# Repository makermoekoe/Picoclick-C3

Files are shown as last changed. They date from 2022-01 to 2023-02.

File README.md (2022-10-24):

# Picoclick-C3

</a>
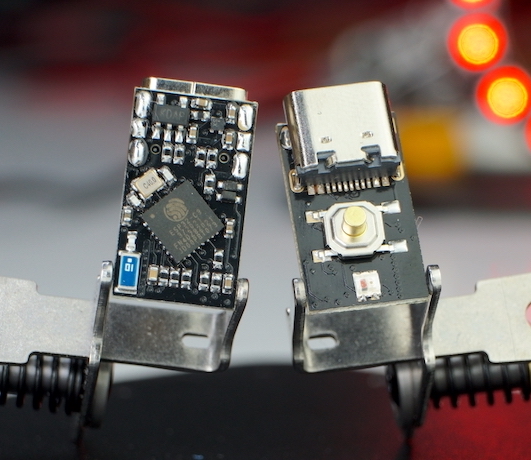
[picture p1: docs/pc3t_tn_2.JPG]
</a>

The Picoclick C3 as well as its little brother (the C3T, T = tiny) are the successors of the well known [Picoclick](https://github.com/makermoekoe/Picoclick). The name is related to its new processor: the [ESP32-C3](https://www.espressif.com/sites/default/files/documentation/esp32-c3_datasheet_en.pdf) single core RISC-V 160MHz CPU.

The Picoclick is a tiny WiFi and BLE IoT button for several applications. Originally designed for smart home things, the Picoclick can also be used as an actuator for IFTTT automations or as an MQTT device. It is based on the single core ESP32-C3 RISC-V processor and therefore comes with tons of useful features.
With dimensions of only 10.5mm by 18mm, the C3T is not only the smallest one in the family of the Picoclicks, it is also the smallest device I have created so far.

The [Youtube video of the C3T](https://www.youtube.com/watch?v=t-50w3RsUlg) shows the assembly and soldering process, the optimization of the boot up time, the power measurements as well as some useful applications of the Picoclick.

Here are some specs of the Picoclick C3T:
- Dimensions are only 10.5x18mm
- Ultra low standby current due to latching circuit (no sleep mode needed)
- Single button & LED interface (WS2812 RGB LED)
- USB Type-C for charging the battery and flashing the ESP32-C3



## Update 14.07.2022: The Picoclick C3 is alive!

It's a pleasure for me to announce that the Picoclick C3 (the big brother of the C3T) is finally here! It comes with the most advanced features of my latest projects which occupies the following points:

- Optimized idle current: we're below 200nA (!!) current consumption (without battery protection) in idle state! (compared to 3µA for the C3T)
- Optimized antenna design, which will lead to a better performance and longer range.
- Optimized power latching circuit, which makes the firmware development easier. (especially with the Arduino IDE)
- Optimized battery charging circuit with separated status LED.
- Added second RTC crystal.
- Added FPC connector for connecting external hardware.
- Added embedded battery protection.
- Added boot emergency jumper.
- Same dimensions as the standard Picoclick.
- Added a nice "golden" logo ;)

### [Main documentation of the Picoclick-C3 can be found here!](https://makermoekoe.gitbook.io/picoclick-c3/)

## GPIOs

Function | GPIO C3T | GPIO C3 | Mode
-------- | -------- | -------- | --------
LED | GPIO6 | GPIO6 (CLK) + GPIO7 (SDI) | Output
Latch* | GPIO3 | ** | Output
Button | GPIO5 | GPIO5 | Input
Charge Stat. | GPIO1  | ext. LED | Input
Bat Voltage | GPIO4 | GPIO4 | Input
Bat Voltage EN | -- | GPIO3 | Output

*Enabling the LDO can be done by pressing the button of the device or turning the latch high. In most use cases, the latch GPIO should be turned on as the first task of the Picoclick. Once the task is completed the device can be powered off by turning the latch off (e.g. pulling it low).

**The Picoclick C3 doesn't need a latching GPIO because it uses the embedded flash's power supply pin as a reference. It can be depowered with putting the ESP32 in deepsleep. To reduce the power consumption of the ESP32 this function will disable the power of the embedded flash (`VDD_SPI`) which in result will depower the Picoclick itself. The deepsleep calling function is only necessary to pulling the `VDD_SPI` line low, not to use the deepsleep mode of the ESP32.

## Reducing power consumption

In order to reduce the power consumption of the Picoclick the following points can be done:

- Disable WiFi while not in use (e.g. if using LED animations only): `WiFi.mode(WIFI_OFF);`
- Reducing CPU frequency after WiFi stuff is completed (crystal is 40MHz): `setCpuFrequencyMhz(10); //reduce to 10MHz`
- Reducing brightness of the LEDs (can be done right after FastLED init): `FastLED.setBrightness(150);`

## Board overview C3T (Battery connections)

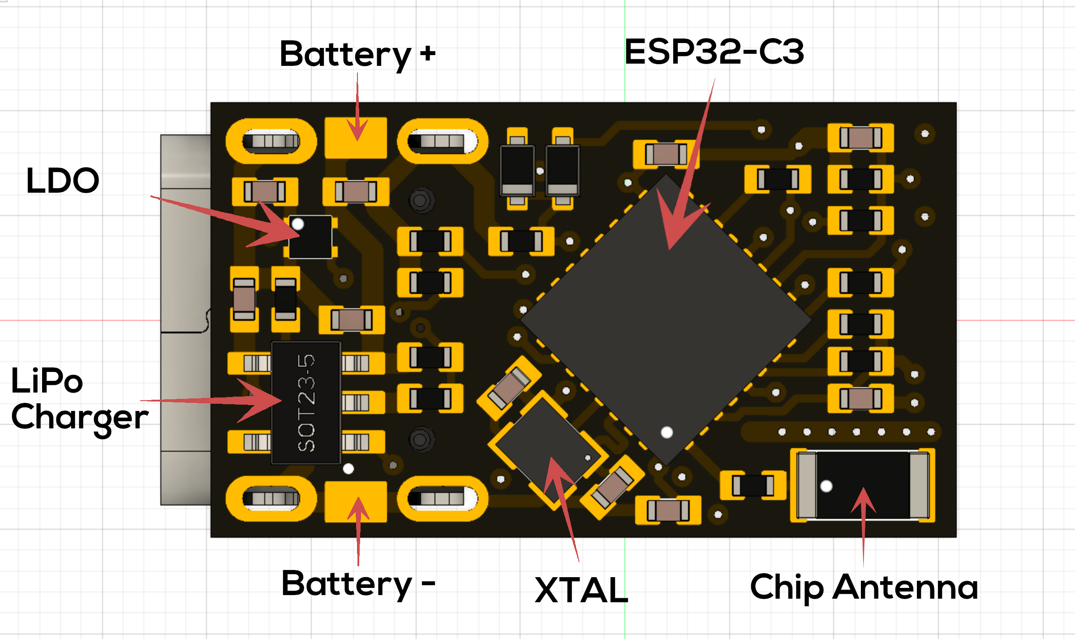
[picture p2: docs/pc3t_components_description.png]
</a>

## Flashing firmware to the ESP32 (C3T)

**- Press and hold the button during the complete flashing process! Otherwise the ESP32 will be loose power and the upload process will crash!**

**- A battery or a power supply has to be applied to the battery pads (3.5v - 5.5v) in order to flash the device!**

Except the above, the Picoclick behaves like a normal development board. No need to get the ESP32 into download mode or pressing any reset button.

## Speed up boot process

**Following instructions are only needed for the C3T, not for the C3 as it doesn't use a separate latching GPIO.**

Due to the latching circuit, the button press has to be longer than the boot up time of the processor, because the first task should have been executed once the button is released. For most of the use cases of the Picoclick the first task is to toggle the latch GPIO high in order to enable power hold feature of the Picoclick. If this task haven't been executed before the button is released, the Picoclick is going to standby mode without finishing its main task.
Standard boot up time of the ESP32-C3 is almost 300ms. So the first task will be executed after these 300ms. This is far too long because a standard button press (especially with the metal buttons on the C3T) is around 100ms-200ms or even slightly below. Almost every task of the Picoclick would have been interrupted in this case (unless you press and hold the button...).
To speed up the boot process I got familiar with the ```menuconfig``` of the ESP-IDF. Actually the reason why I've switched from the Arduino framework to ESP-IDF was that I get access to all the configs of the ESP32-C3.

Things I have done so far:
- Set *Flash SPI mode* from *DIO* to *QIO* (in Serial flasher config)
- Set *Log output* from *Info* to *Warning* (in component config)
- Set *Bootloader log verbosity* from *Info* to *Warning* (in Bootloader config)
- Enable *Skip image validation from power on* (in Bootloader config)

These points result in a boot up time of around 68ms which is almost quite fantastic. The test I've done so far were quite sufficient. If it is possible to make it even faster or if you have other ideas which could lead into the right direction then please let me know!

## Power consumption C3T

These power measurements are done with the Otii Arc power analyzer and its dedicated software. The average and peak current can be seen in the top right corner and is based on the selected frame in the current graph.
The Picoclick C3T is used as an ESP-NOW slave in this case, which is probably the fastest solution of any wireless connection.

A complete Picoclick task will look like this, whereby the LED part in the end is the longest part. The whole task took about 1,7 seconds, but the transmission itself is completed after around 200ms. The other part is with disabled WiFi and only used to do some visualizations with the LED. Overall average current is below 28mA.

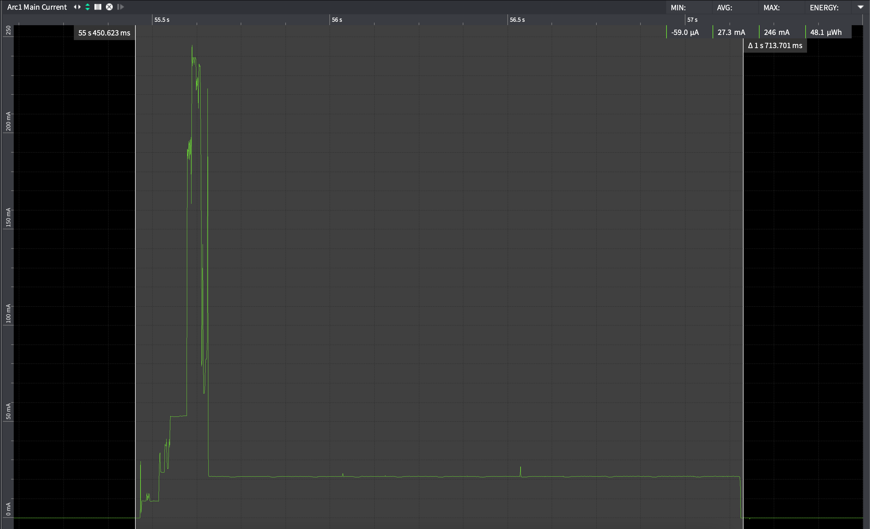
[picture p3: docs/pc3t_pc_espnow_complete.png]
</a>

The ESP-NOW package is sent in the first 200ms. Average current is 73mA here.

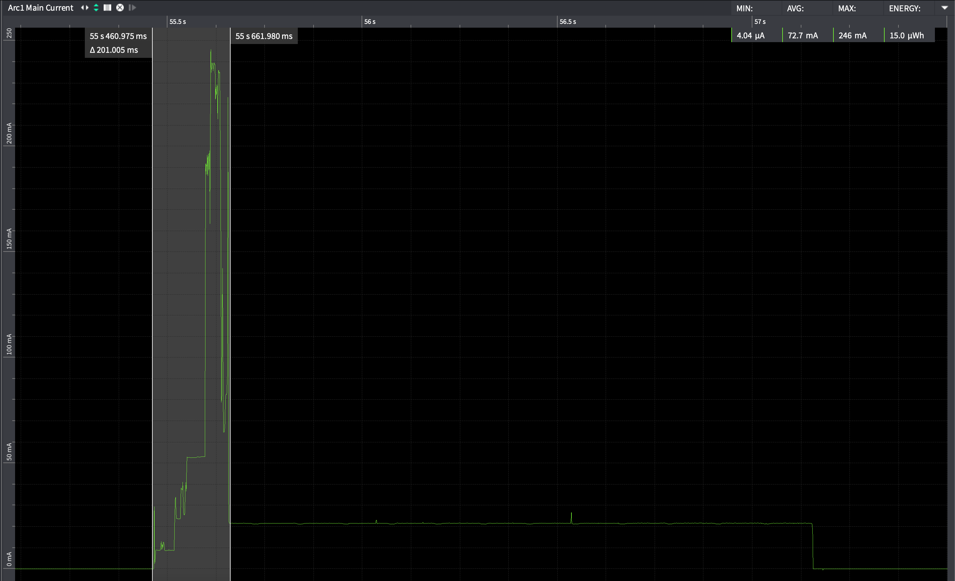
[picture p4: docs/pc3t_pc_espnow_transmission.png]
</a>

As already said, the rest is just visualization stuff which will use 22mA of current in average.

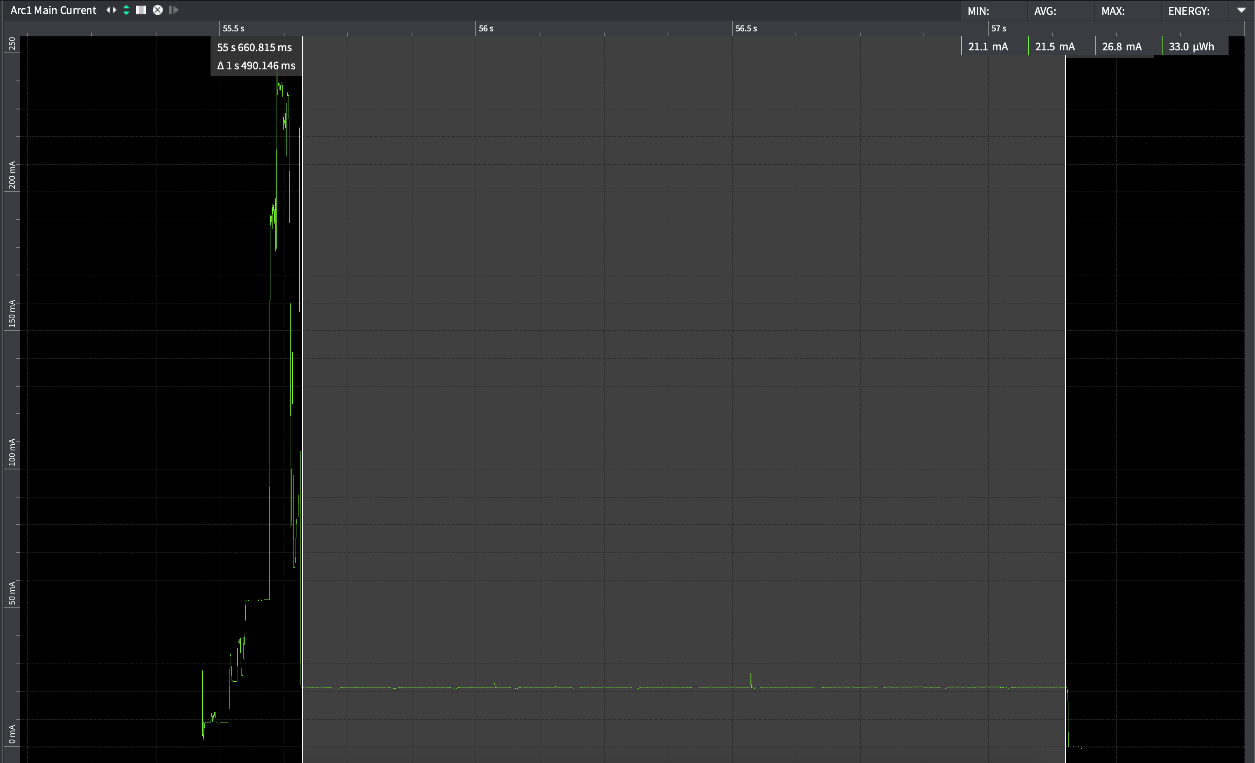
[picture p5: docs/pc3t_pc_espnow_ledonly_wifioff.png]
</a>

Probably the most interesting part is the standby current, because it's the most used state of the Picoclick. As the device doesn't use any sleep mode, we're getting as low as 3µA in this state. This is only related to the battery monitoring feature. As the voltage divider between ```Vbat``` and ```GND``` is ```1MOhm + 250kOhm = 1.25MOhm``` the current flow through it is about 3µA.

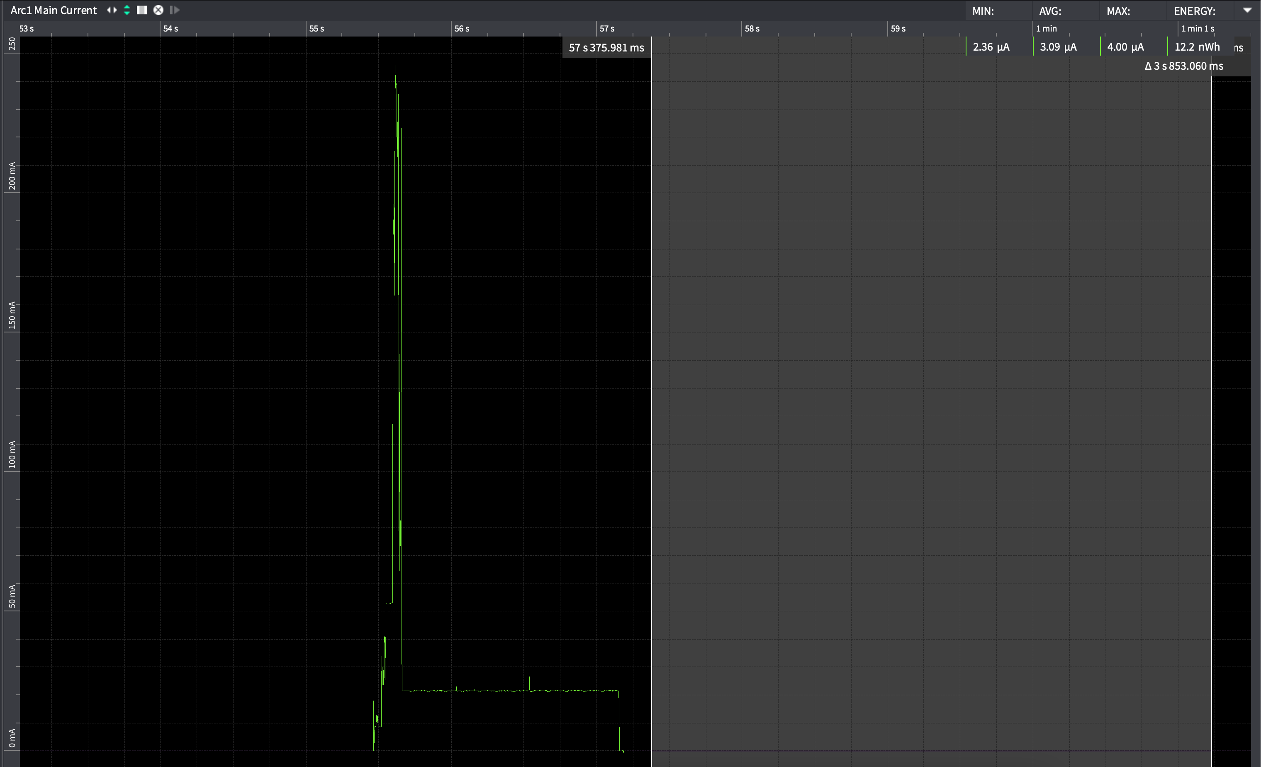
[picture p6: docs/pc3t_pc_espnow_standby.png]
</a>

## Battery for the Picoclick

### C3T

The optimal battery, which is shown in the picture below, is a 301012 LiPo battery (3.0mm thick, 10mm width, 12mm length). Nevertheless you can use whatever single cell LiPo battery you want. Charging current is set to 20mA, to be used with those 20-30mAh batteries. For larger capacity batteries the battery charging time will - of course - increase. For 20-30mAh charging time is about 1h - 1,5h.

Below are some links for those tiny batteries (no sponsor, no affiliate, just for info):

[Aliexpress 301012](https://de.aliexpress.com/item/1005003644834180.html)

[Aliexpress 401012](https://de.aliexpress.com/item/32794940086.html)

[eBay 301012](https://www.ebay.com/itm/333907143841)

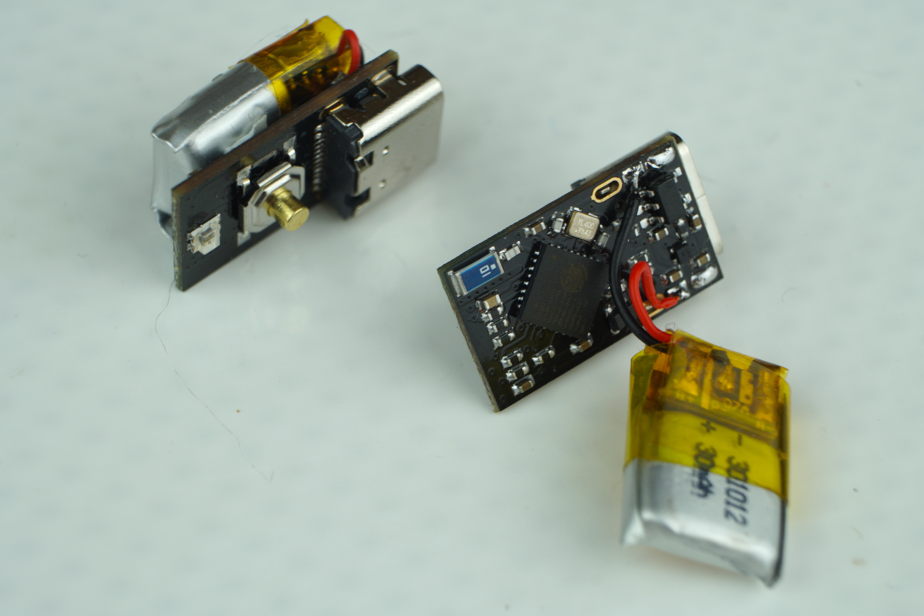
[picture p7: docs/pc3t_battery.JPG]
</a>

### C3

As the Picoclick C3 comes with an embedded battery protection, the protection of the LiPo battery itself is redundant. Therefore you can use these tiny cells which are used by BT headsets. They come in a 401010 or 301010 package.

[Aliexpress 401010](https://de.aliexpress.com/item/1005004324462178.html)

## Flashing adapter with pogopins for the C3T

In order to flash boards without soldering wires or batteries to the Picoclick, I decided to print a simple flashing adapter which uses 1mm pogopins to make contact to the battery pads on the board. Just plug in the USB cable, shift the device in, press it down to the pogopins and hit the upload button. Simple overview is given below.

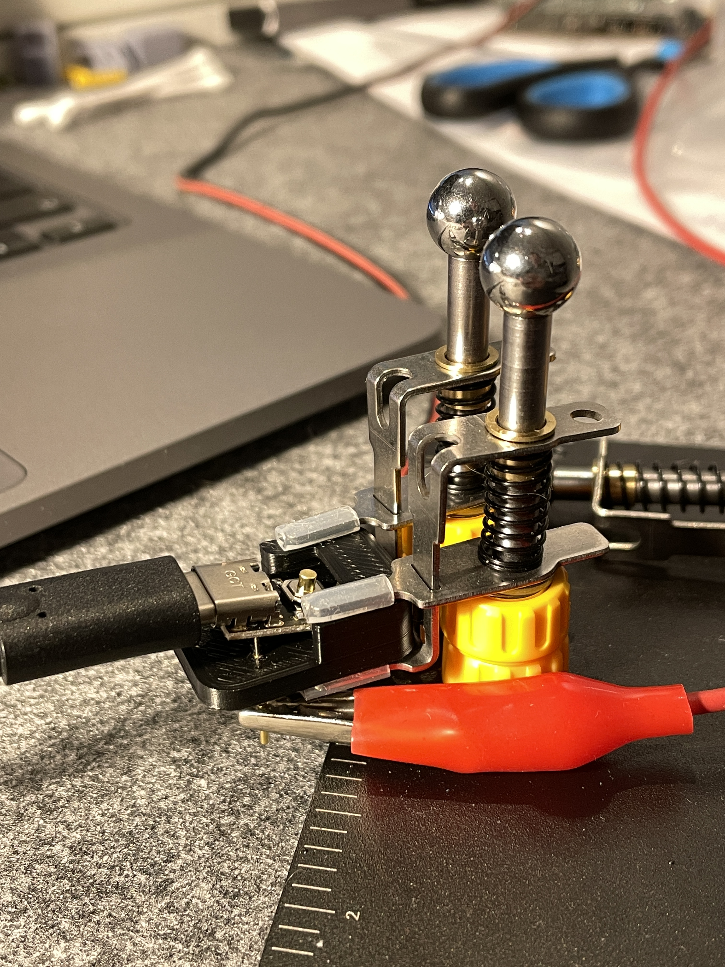
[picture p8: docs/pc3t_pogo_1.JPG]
</a>
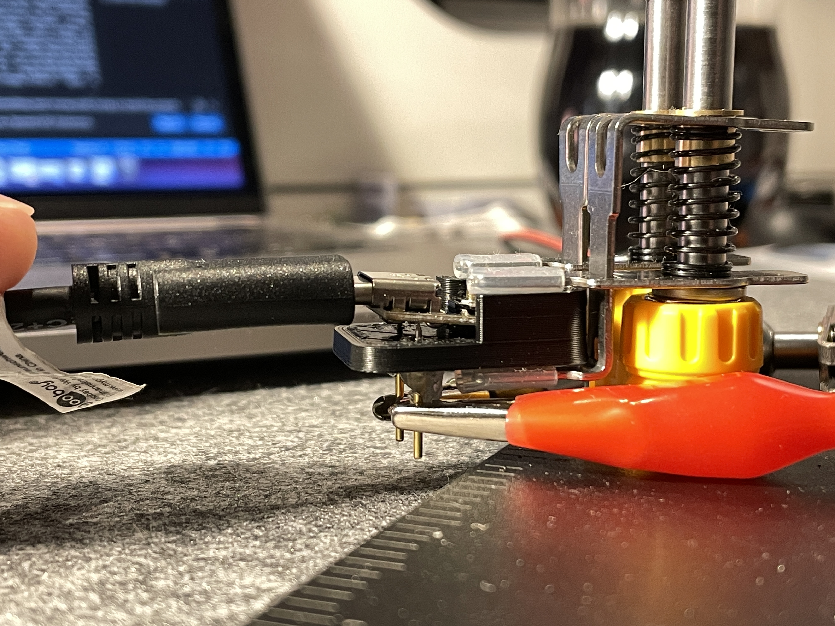
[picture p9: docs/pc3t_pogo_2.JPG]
</a>

## Cases for the C3T

Round design. Combined with two M2x8mm screws.

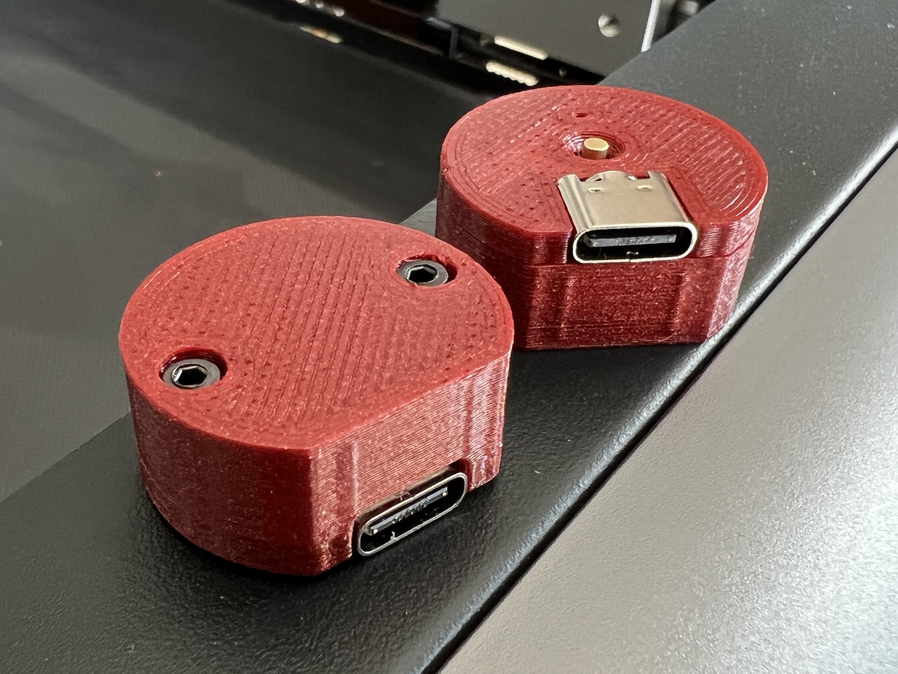
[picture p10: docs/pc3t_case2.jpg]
</a>

# FAQ

## My Picoclick C3T is not shown on the device list when I plug it in the computer - what can I do?
- Your Picoclick is well tested before shipping, so it is probably not broken. Make sure you have connected a decent power supply to the battery connections (3.5v - 5.5v). Battery polarity is shown above. The USB-C jack is only for charging the battery and to flash the ESP32 - not for powering the device.

## Media

Hackster.io article by James Lewis: [Picoclick C3T Is the World's Smallest IoT Button and It Has a RISC-V Processor](https://www.hackster.io/news/picoclick-c3t-is-the-world-s-smallest-iot-button-and-it-has-a-risc-v-processor-7eddb2c14bda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)

Electronics-lab.com article by Abhishek Jadhav: [Picoclick C3T IOT button built around ESP32-C3 RISC-V processor – supports WIFI and BLE](https://www.electronics-lab.com/picoclick-c3t-iot-button-built-around-esp32-c3-risc-v-processor-supports-wifi-and-ble/)

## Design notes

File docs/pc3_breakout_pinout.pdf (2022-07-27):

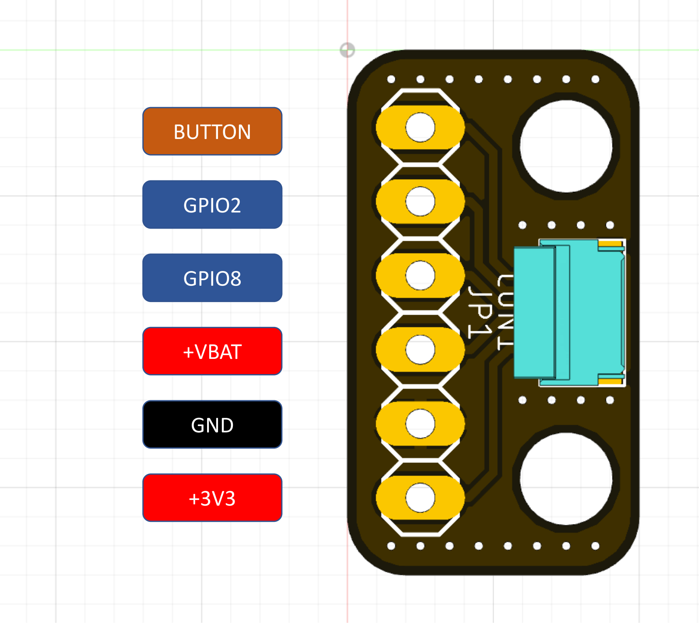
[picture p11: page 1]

+3V3

+VBAT

GND

GPIO2

GPIO8

BUTTON

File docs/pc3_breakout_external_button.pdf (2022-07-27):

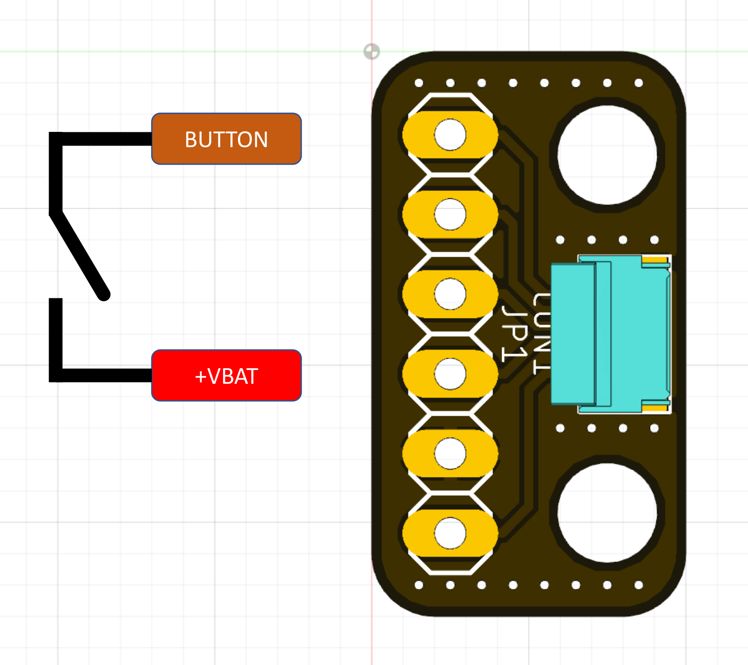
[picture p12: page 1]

+VBAT

BUTTON

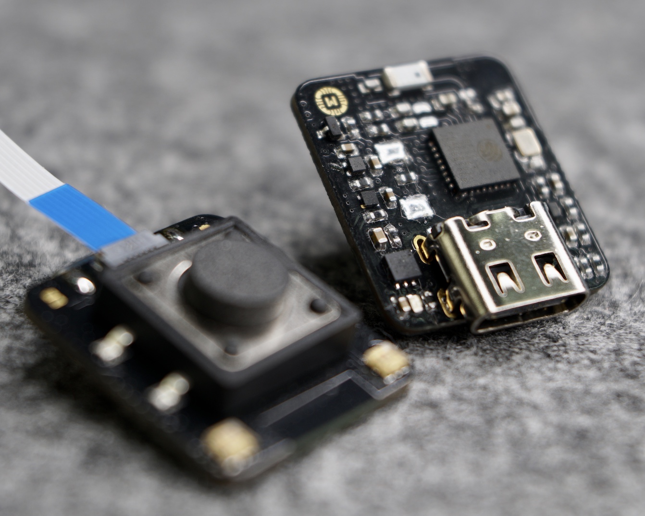
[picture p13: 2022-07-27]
docs/pc3_overview.jpg

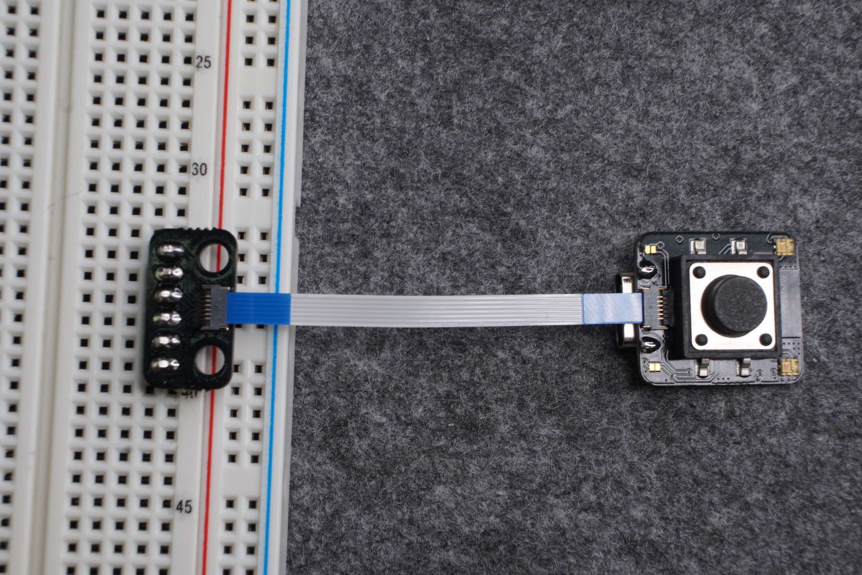
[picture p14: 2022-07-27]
docs/pc3_extensionboard.JPG

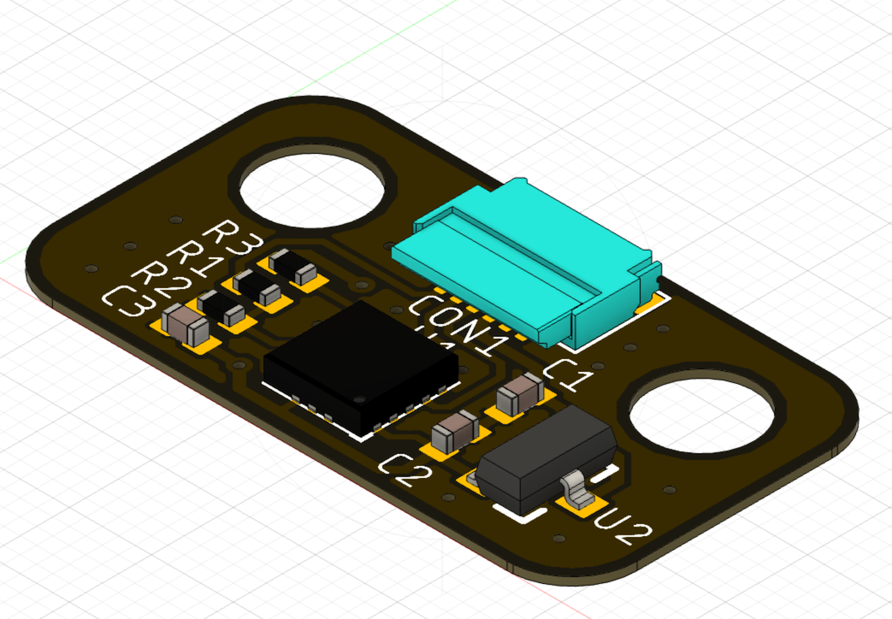
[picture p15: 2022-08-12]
docs/ext_board_lis.png

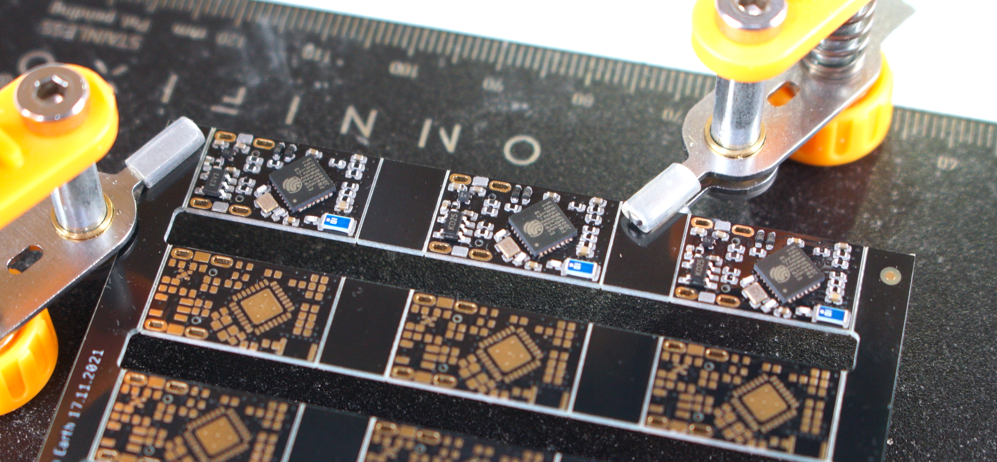
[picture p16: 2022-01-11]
docs/pc3t_panel_paste.JPG

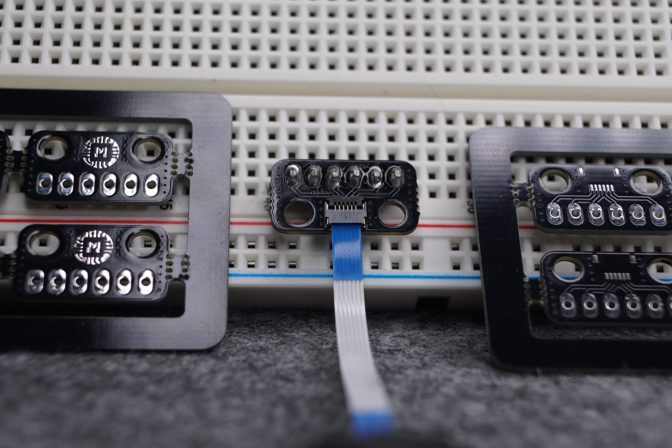
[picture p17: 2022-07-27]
docs/pc3_extensionboard2.JPG

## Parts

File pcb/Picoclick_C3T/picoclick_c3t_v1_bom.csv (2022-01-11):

Part | Value | Device | Package | Description
BAT+ | TP/SP-1.5X1.0 | TP/SP-1.5X1.0 | SOLDERPAD_1.5X1.0 | Solderpads/Testpads
BAT- | TP/SP-1.5X1.0 | TP/SP-1.5X1.0 | SOLDERPAD_1.5X1.0 | Solderpads/Testpads
C1 | 1µ | C-EU-0402-WOKEEPOUT_S | C0402_S
C2 | 1µ | C-EU-0402-WOKEEPOUT_S | C0402_S
C3 | 1µ | C-EU-0402-WOKEEPOUT_S | C0402_S
C4 | 1µ | C-EU-0402-WOKEEPOUT_S | C0402_S
C7 | 10µ | C-EU-0402-WOKEEPOUT_S | C0402_S
C8 | 0,1µ | C-EU-0402-WOKEEPOUT_S | C0402_S
C9 | 0,1µ | C-EU-0402-WOKEEPOUT_S | C0402_S
C13 | 1µ | C-EU-0402-WOKEEPOUT_S | C0402_S
C20 | 10p | C-EU-0402-WOKEEPOUT_S | C0402_S
C21 | 10p | C-EU-0402-WOKEEPOUT_S | C0402_S
D1 | 4148 | DIODE-SOD523 | SOD523 | DIODE
D2 | 4148 | DIODE-SOD523 | SOD523 | DIODE
ESP1 | ESP32_C3_QFN32 | ESP32_C3_QFN32 | QFN32
F2 | 0 | R-EU-0402-WOKEEPOUT | R0402
L1 | WS2812_2020 | WS2812_2020 | WS2812_2020
R/1 | 1M | R-EU-0402-WOKEEPOUT | R0402
R/2 | 250k | R-EU-0402-WOKEEPOUT | R0402
R1 | 1k | R-EU-0402-WOKEEPOUT | R0402
R2 | 1k | R-EU-0402-WOKEEPOUT | R0402
R3 | 1M | R-EU-0402-WOKEEPOUT | R0402
R4 | 10k | R-EU-0402-WOKEEPOUT | R0402
R5 | 47.5k | R-EU-0402-WOKEEPOUT | R0402
R7 | 10k | R-EU-0402-WOKEEPOUT | R0402
R10 | 10k | R-EU-0402-WOKEEPOUT | R0402
R11 | 10k | R-EU-0402-WOKEEPOUT | R0402
R12 | 5.1k | R-EU-0402-WOKEEPOUT | R0402
R13 | 5.1k | R-EU-0402-WOKEEPOUT | R0402
RF | ANT3216LL00R2400A | ANT3216LL00R2400A | ANT3216LL00R2400A
U$1 | BUTTON_ST-1187-3 | BUTTON_ST-1187-3 | BUTTON_ST-1187-3
U1 | BRCL4054BME | MCP73831_SOT23_5 | SOT23-5
U2 | MIC5504 | MIC5504 | TDFN4
USB-C | USB_C_C393939 | USB_C_C393939 | USBC_C393939
X1 | XTAL_2016 | XTAL_2016 | XTYL_2016

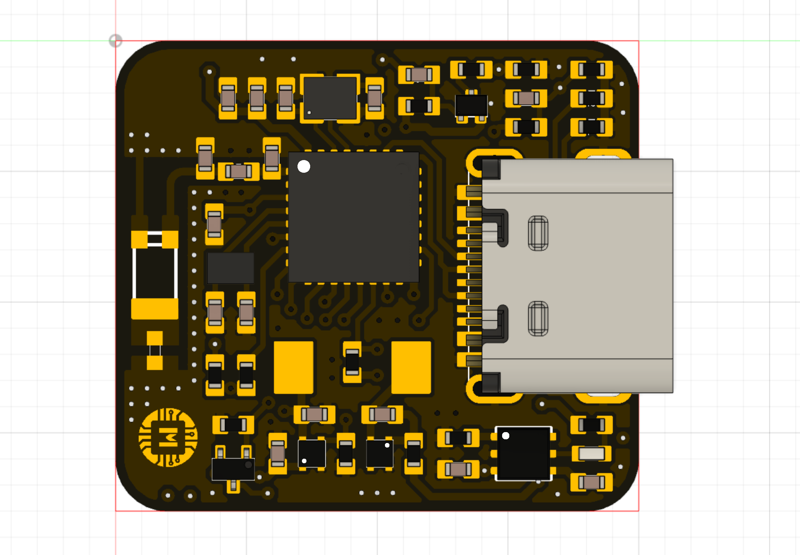
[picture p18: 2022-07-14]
docs/pc3_components_description.png

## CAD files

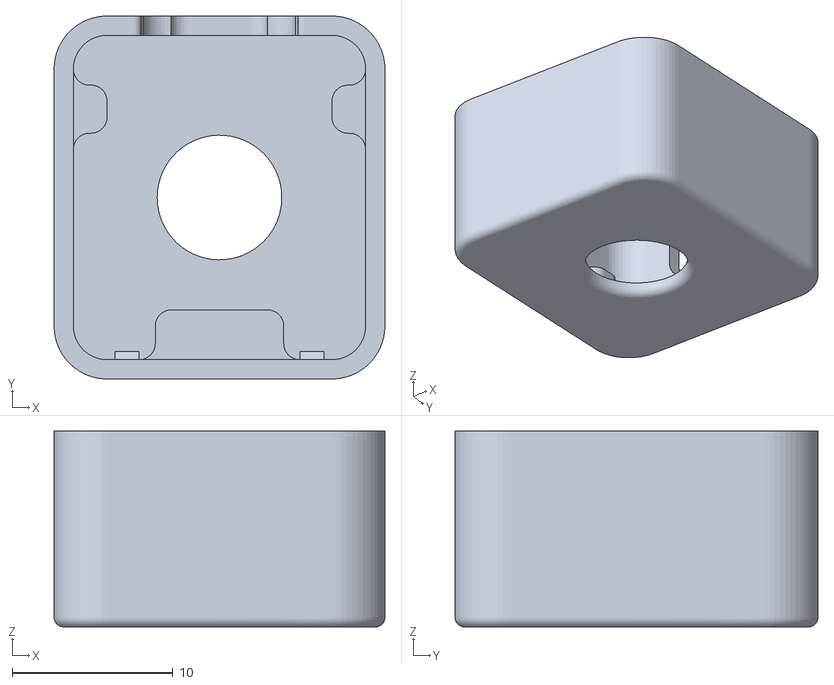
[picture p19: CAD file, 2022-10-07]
case/Picoclick_C3/case1_clear/picoclick_c3_clear_top_batspace_lock.stl
20.6 x 22.6 x 12.2

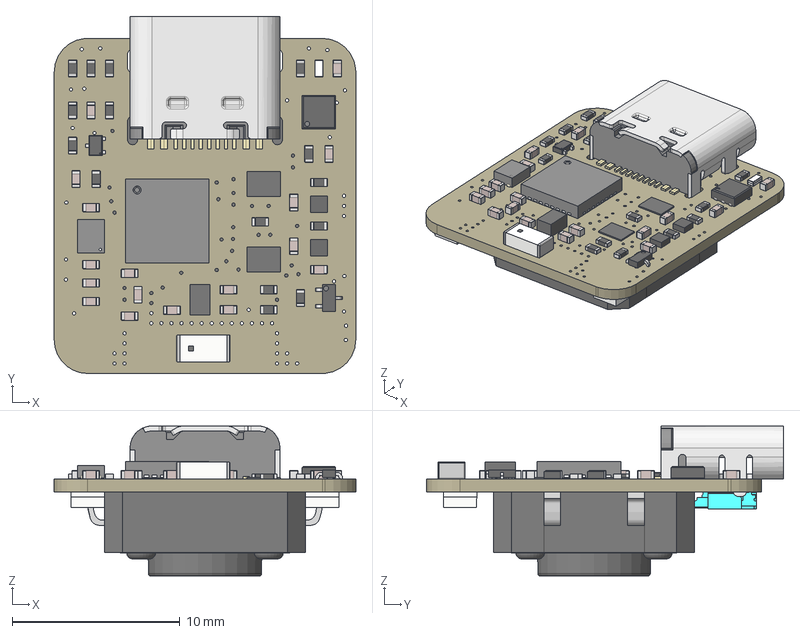
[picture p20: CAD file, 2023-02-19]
case/Picoclick_C3/PC3_3Dmodel.step
18.0 x 21.3 x 8.95 mm
Board
QFN32
SOT523
SOT723+1123
XTAL_2016
FH34SRJ-6S-0.5SH(50)
ConPins
PcbPins
Mold
Frame
DFN-6
TDFN4
Light
Cathode Mark
Anode Pin
Cathode Pin
Base
JUMPER_SMALL
BUTTON_SMD_12MM
JUMPER_SMALL (1)
R0402 (1)
TDFN4 (1)
XTAL_1016
SOLDERPAD_1.5X2.0 x 2
RFECA3216060A1T_NEW3_M
C0402_S x 14
R0402 x 14
C0402_S (1) x 3

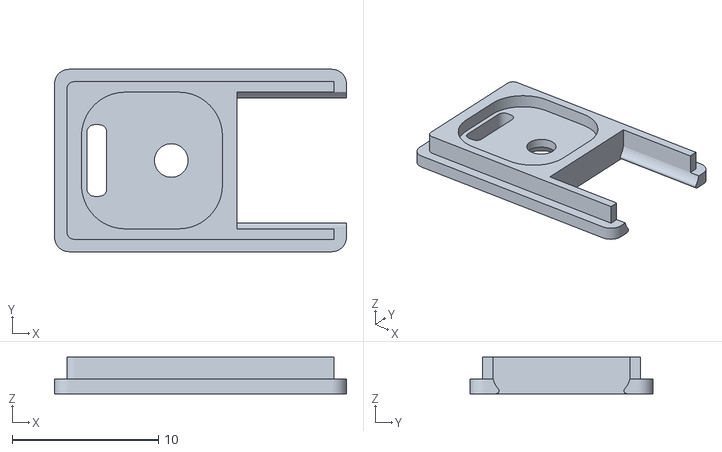
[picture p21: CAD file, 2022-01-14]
case/Picoclick_C3T/case1/pc3t_case1_top.stl
20.0 x 12.5 x 2.50

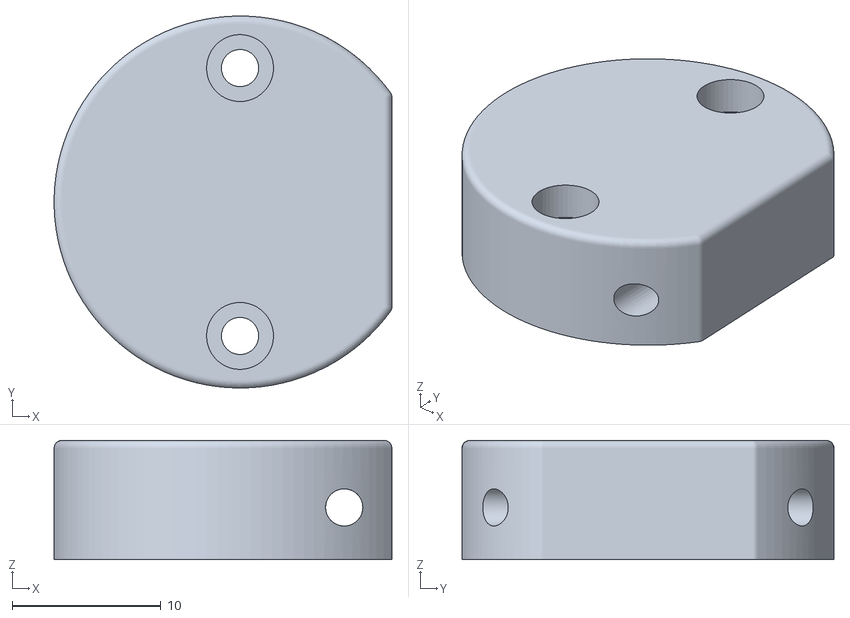
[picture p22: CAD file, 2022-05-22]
case/Picoclick_C3T/case2_round/pc3t_case2_round_bot_keyring2.stl
22.7 x 25.0 x 8.00

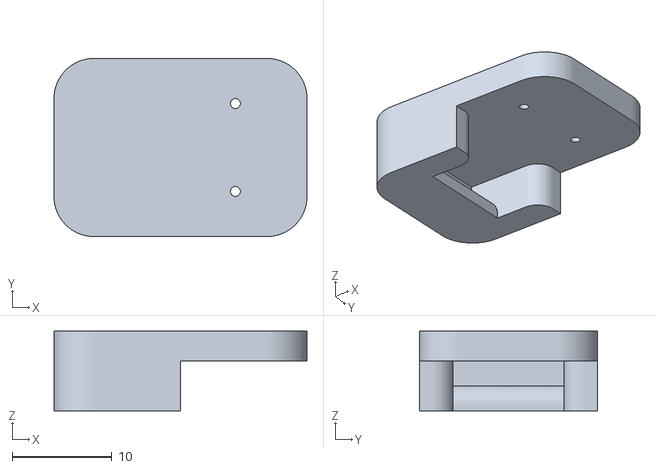
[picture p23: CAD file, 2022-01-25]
case/Picoclick_C3T/Picoclick_C3T_Flash_Pogo_Adapter.stl
25.3 x 17.8 x 8.00

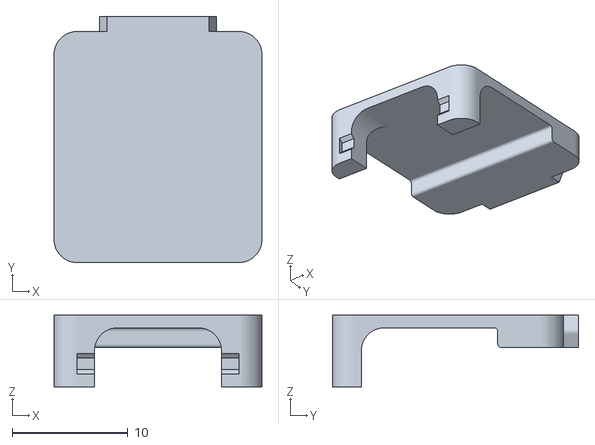
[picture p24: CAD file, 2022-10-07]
case/Picoclick_C3/case1_clear/picoclick_c3_clear_bot_batspace_lock.stl
18.0 x 21.3 x 6.21

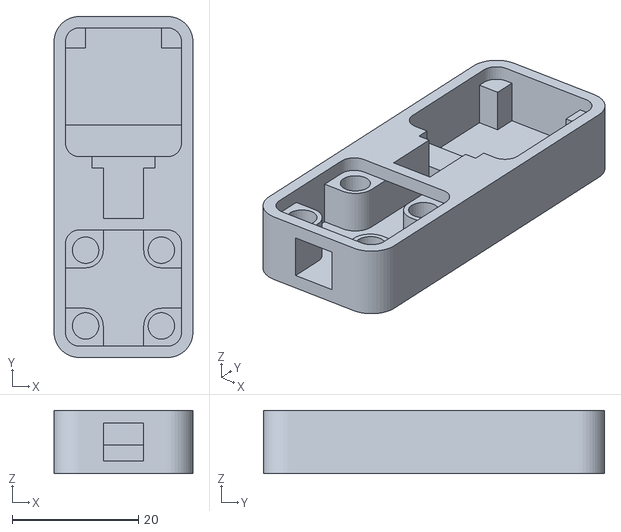
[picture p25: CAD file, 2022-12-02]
case/Picoclick_C3/pc3_ext_pir_v1.stl
22.0 x 54.0 x 10.00

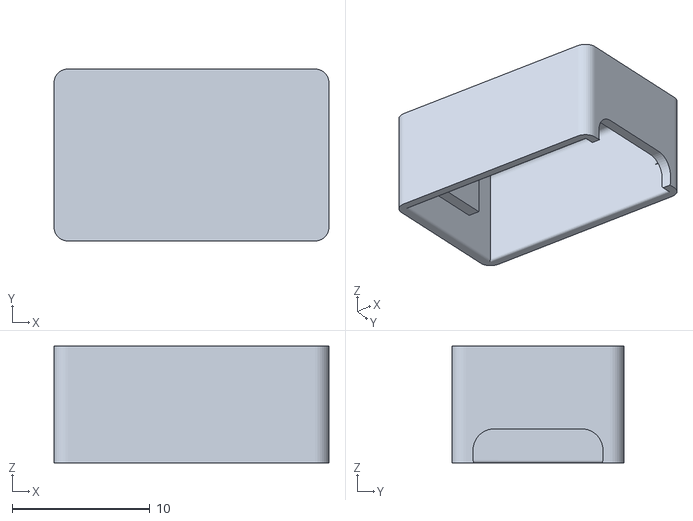
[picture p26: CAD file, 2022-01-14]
case/Picoclick_C3T/case1/pc3t_case1_bot.stl
20.0 x 12.5 x 8.50

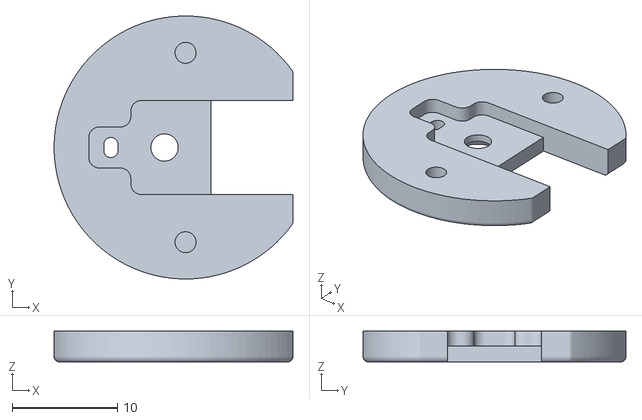
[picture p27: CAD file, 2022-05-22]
case/Picoclick_C3T/case2_round/pc3t_case2_round_top.stl
22.7 x 25.0 x 2.93

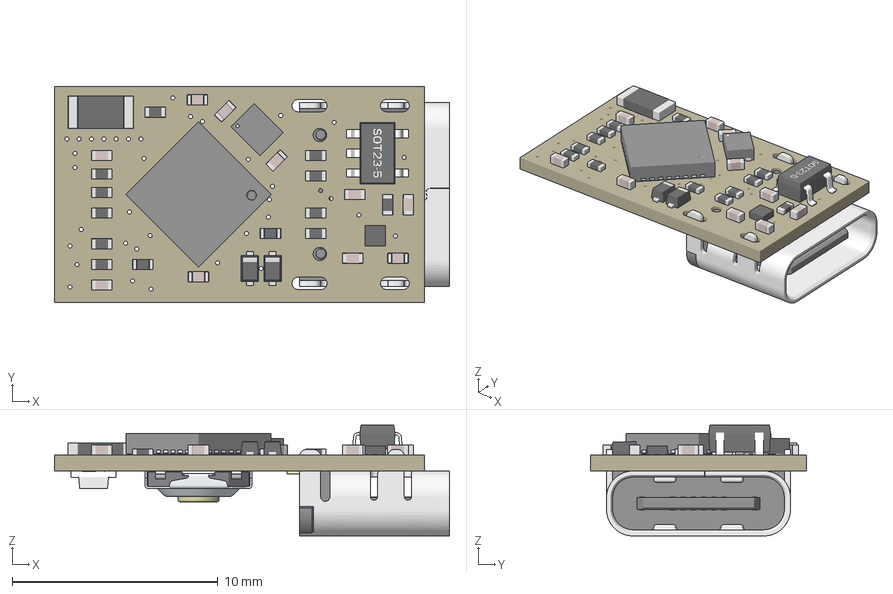
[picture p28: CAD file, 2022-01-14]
case/Picoclick_C3T/Picoclick_C3T_PCB.3mf
19.2 x 10.5 x 5.39 mm
Board
Körper1 x 36
Körper10
Körper11
Körper12
Körper13
Körper14
Körper15
Körper16
Körper17
Körper18
Körper19
Körper2 x 2
Körper20
Körper21
Körper22
Körper23
Körper24
Körper25
Körper26
Körper27
Körper28
Körper29
Körper3 x 2
Körper30
Körper31
Körper32
Körper33
Körper34
Körper35
Körper36
Körper37
Körper38
Körper39
Körper4 x 2
Körper40
Körper41
Körper42
Körper43
Körper44
Körper45
Körper46
Körper47
Körper48
Körper49
Körper5 x 2
Körper50
Körper51
Körper52
Körper53
Körper54
Körper55
Körper56
Körper57
Körper58
Körper59
Körper6 x 2
Körper60
Körper61
Körper62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

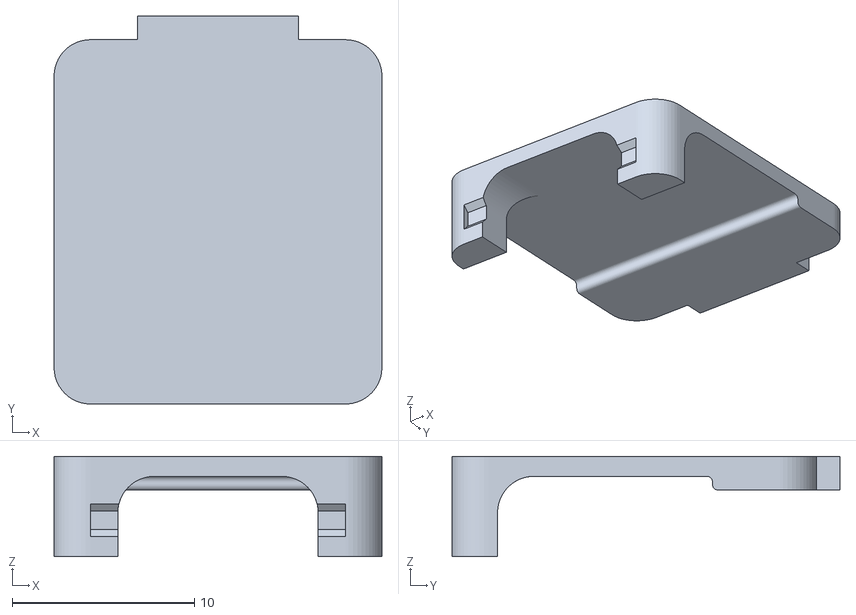
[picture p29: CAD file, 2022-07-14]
case/Picoclick_C3/case1_clear/picoclick_c3_clear_bot.stl
18.0 x 21.3 x 5.51

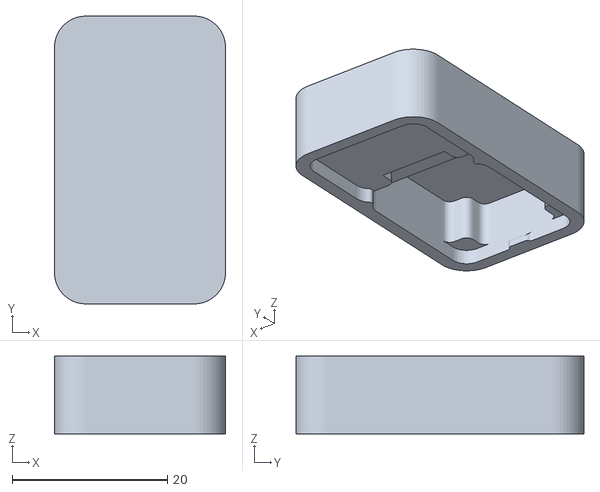
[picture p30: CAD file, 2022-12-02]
case/Picoclick_C3/pc3_ext_oled049_v1.stl
22.0 x 37.0 x 10.00

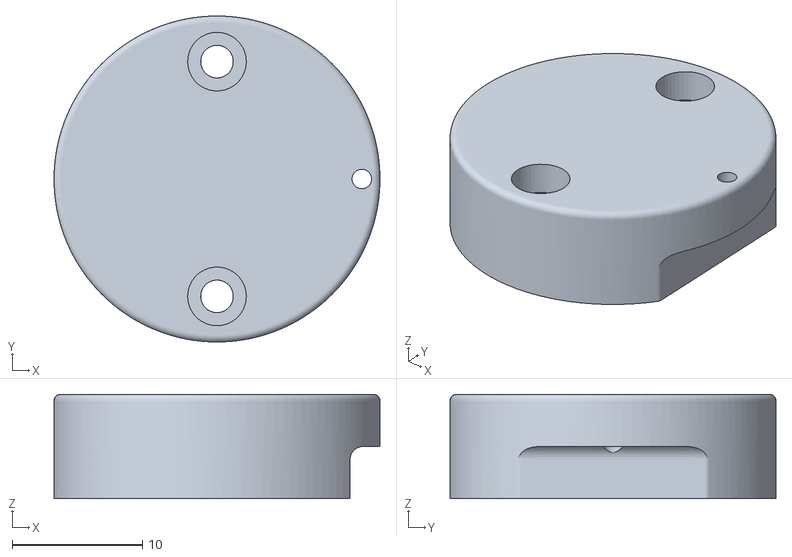
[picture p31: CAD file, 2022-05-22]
case/Picoclick_C3T/case2_round/pc3t_case2_round_bot_keyring1.stl
25.0 x 25.0 x 8.00

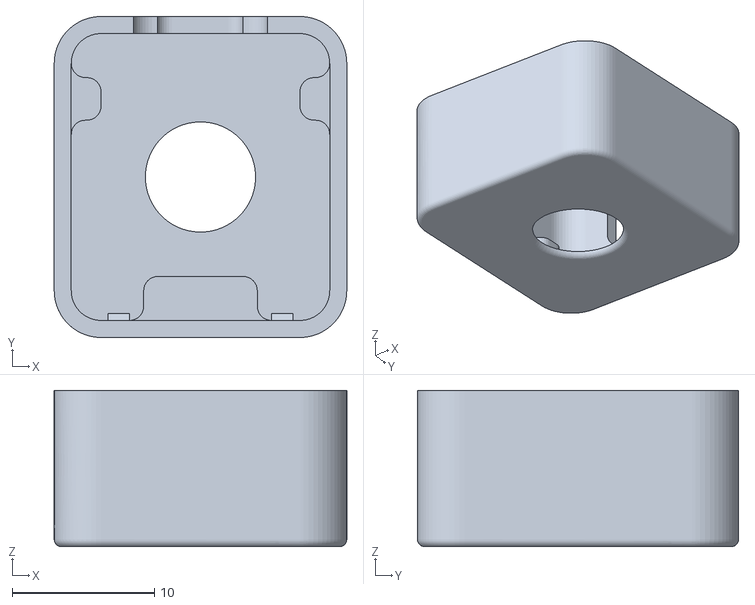
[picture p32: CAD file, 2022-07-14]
case/Picoclick_C3/case1_clear/picoclick_c3_clear_top.stl
20.6 x 22.6 x 11.0

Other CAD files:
case/Picoclick_C3/pc3_ext_motion_v2.stl
case/Picoclick_C3T/case2_round/pc3t_case2_round_bot.stl
case/Picoclick_C3/pc3_pogopin_adapter_bat_v1.stl
case/Picoclick_C3T/Picoclick_C3T_PCB.f3z
case/Picoclick_C3T/Picoclick_C3T_PCB.stl

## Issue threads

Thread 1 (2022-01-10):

Where can I buy one or two

8bignic8, 2022-01-10:
Hey is it possible to buy one or more. We could use it in our Hackerspace :). Greetings nice project.

makermoekoe, 2022-01-11:
Currently working on my own tindie store. It should be available in a couple of days. Nevertheless, I'm currently waiting for some components to arrive so the stock is not huge at the moment but will increase in 2-3 weeks.

Closed 2022-01-11.

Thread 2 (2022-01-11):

Have BOM list ?

Witawat, 2022-01-11:
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
What part F1 and F2 ?

thankyou

frollard, 2022-01-11:
https://www.espressif.com/sites/default/files/documentation/esp32-c3_hardware_design_guidelines_en.pdf

page 11: section 2.5 RF hardware design notes - "add a pi matching network for antenna matching, preferably CLC network." Parts tbd based on actual pcb.

makermoekoe, 2022-01-11:
Tradeoff between device size and fully matchable antenna. So it's not a complete pi network but nevertheless seems to work fine for this four layer board with its dimensions.

BOM is added.

Closed 2022-01-11.

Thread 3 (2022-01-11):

Not espressif but impressive

pshobowale, 2022-01-11:
1.) On the question if you could improve the performance:
Are there still boot messages if you look at the serialport? Because if there are you could try to completely disable them as this wastes time during startup. --> https://esp32.com/viewtopic.php?t=24244 and https://www.esp32.com/viewtopic.php?t=1658 (don't know if it is the same procedure as for the c3)

2.) How much longer is the boot time if you validate the boot image, because this could be a possible backdoor?

3.) May I use you your design for a private project? (I want to try to build a kind of opensource alternative to this --> https://freedrum.rocks/)

septatrix, 2022-01-19:
You could also take a look inside the [`esp_system/startup.c`](https://github.com/espressif/esp-idf/blob/1d02e638bd05b80d6fd648d51c14a8ecd6c2dbdc/components/esp_system/startup.c)¹ file and try some of the other hooks there. It seems like using `__attribute__(constructor)`, `__attribute__ ((section(".initX"))` or `ESP_SYSTEM_INIT_FN` should all provide you with earlier places to enable the power latch. The earliest hook seems to be to define a custom `start_cpu0` and inside that call `start_cpu0_default` to continue the normal boot process. I am not quite sure if some initialization has to be performed before the gpio is usable via the usual functions so some of the more drastic/early hooks might not work or you would need to write to the raw registers instead. Anyway if you want to register even shorter button presses this might help. If you have any question feel free to ask me (also in german ;D).

¹ Potentially also [`esp_system/port/cpu_start.c`](https://github.com/espressif/esp-idf/blob/1d02e638bd05b80d6fd648d51c14a8ecd6c2dbdc/components/esp_system/port/cpu_start.c) though I doubt you can hook into there - also the system is very much uninitialized that early.

makermoekoe, 2022-01-24:
There aren't any messages while the ESP is booting anymore. Nevertheless, the easier way is to disable them completely, yes...

I don't now it anymore because I have tested so many things on that day back then. I should definitely measure it again and check if it's worth it.

And as I have not yet set any license here you can actually use whatever you want!

makermoekoe, 2022-01-24:
> You could also take a look inside the [`esp_system/startup.c`](https://github.com/espressif/esp-idf/blob/1d02e638bd05b80d6fd648d51c14a8ecd6c2dbdc/components/esp_system/startup.c)¹ file and try some of the other hooks there. It seems like using `__attribute__(constructor)`, `__attribute__ ((section(".initX"))` or `ESP_SYSTEM_INIT_FN` should all provide you with earlier places to enable the power latch. The earliest hook seems to be to define a custom `start_cpu0` and inside that call `start_cpu0_default` to continue the normal boot process. I am not quite sure if some initialization has to be performed before the gpio is usable via the usual functions so some of the more drastic/early hooks might not work or you would need to write to the raw registers instead. Anyway if you want to register even shorter button presses this might help. If you have any question feel free to ask me (also in german ;D).
>
> ¹ Potentially also [`esp_system/port/cpu_start.c`](https://github.com/espressif/esp-idf/blob/1d02e638bd05b80d6fd648d51c14a8ecd6c2dbdc/components/esp_system/port/cpu_start.c) though I doubt you can hook into there - also the system is very much uninitialized that early.

You genius. Initially the voltage divider workaround and then the idea with the early switching latch haha! Yes, I have read something about the second stage bootloader and that it is possible to do actions there as well. Regarding the serial output while booting this action would take place after 27ms. And when disabling serial output this would even be more early. But as I'm new to the ESP-IDF this is a task in the future only...

Not sure if you have ordered a Picoclick, but if yes it would be nice to get support in this 🙂

septatrix, 2022-01-24:
> You genius. Initially the voltage divider workaround and then the idea with the early switching latch haha!

Thanks, I feel flattered :)

> Not sure if you have ordered a Picoclick, but if yes it would be nice to get support in this 🙂

Not currently, no. I wanted to wait if there might be some hardware revision should the voltage divider be improvable or maybe even slightly modify the board to allow for two buttons and build it myself to save a few bucks.

However I have a normal ESP32 lying around with which I could try some stuff. I won't be able to get any absolute timings as I have no access to an osci but I already have some other ideas in mind to get relative timings.

septatrix, 2022-01-24:
> And as I have not yet set any license here you can actually use whatever you want!

As far as I know you retain every right to the content in this repo without a license meaning that redistributing, modifying etc is prohibited (https://opensource.stackexchange.com/a/1721). I am not well versed with hardware licenses though there should also be some permissive ones you might consider choosing from.

septatrix, 2022-02-12:
The entry points I initially planned to target only yielded small improvements of a few milliseconds at most while being very hacky and using undocumented/internal apis.
However the second stage bootloader seems very promising as it exposes a before/after hook which can be used. The `bootloader_before_init` hook fires after only 850210 cycles on my standard ESP32 which would be about ~5ms@160MHz. The RISC-V core will differ slightly though likely not by much. Sadly I have not been able to convince PlatformIO to also build the second stage bootloader but when directly using idf.py everything seems to work flawless.
Next steps would be to configure some IO pins as the normal GPIO component is not yet initialized so we have to access the registers directly. This should be fairly simply.

I also made an issue about more init hooks before stumbling upon the bootloader hooks where @igrr also suggested simply using a GPIO pin which defaults to a weak pull-up. This could then be made into a low output to disable the latch again. I do not quite grasp the whole latching mechanism and therefore do not know if such a weak pull-up would be sufficient (or if a pull-down would be required which does not seem to be the default state for any of the pins). For anyone interested here the issue: https://github.com/espressif/esp-idf/issues/8390

Closed 2022-04-19.

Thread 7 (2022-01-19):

Rotary Encoder Push Button

paulwratt, 2022-01-19:
Is there enough room (GPIO) to adapt this board this to either:
- rotary encoder
- rotary encoder with push button

DuckDuckGo: [electronics rotary push button](https://duckduckgo.com/?q=electronics+rotary+push+button)

Cheers

Paul

Closed 2022-02-15.

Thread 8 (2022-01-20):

Is the battery voltage checked anywhere?

septatrix, 2022-01-20:
In the README it says that most standby current is used by the voltage divider connected to the battery which according to the schematics is connected only to the ESP32. However in the code I can find no usage of that pin except for the defines. Is there maybe some other place where this information is used? I plan to create my own iot button inspired by you project and if it is not need I consider dropping the voltage divider.

makermoekoe, 2022-01-21:
Well, the battery divider is not needed when don't care about the battery state. It's there to read the batteries voltage level und thus estimate the state of the battery (like in percentage). You could, for example, disable WiFi if the battery state is too low to protect it from being overdischarged, or it least discharged too much, because there is a battery protection which protects it from overdischarge. Another example is to send the battery state out so that you can visualize it somewhere else, like it is also done with smart home remotes or PIRs.

In the included sketches the battery state is not used yet, yes, but I will update this as soon as possible (hopefully on this weekend). It's as easy as reading the GPIO4 (ADC1_CH4) and convert it to a voltage with consideration to the divider.

septatrix, 2022-01-21:
Thanks for the reply. So if it is only used by the ESP32 would it not be possible to put a low-leakage transistor between the voltage divider and ground or connect the ground of the voltage divider to a pin of the ESP32 which could be pulled low when needed¹? Given that it draws a majority of the standby current it would increase the lifetime per charge significantly.

¹ This would of course only work if the GPIO would be in input or high-impedance mode when unpowered though I have not yet found official information regarding that behaviour.

makermoekoe, 2022-01-24:
For the first version of the Picoclick (not the C3 version) I tried to connect the voltage divider to a GPIO on the GND side and turn it low while reading the voltage. Somehow I took a wrong GPIO (probably a floating or a default low one), which was so frustrating that I didn't reconsider working on this again...
But now, as it is clear that it was just a wrong chosen GPIO, I will definitely try to implement something like this again! 3µA are still too much...

Btw. I have updated the code which can now read the battery voltage. It is as easy as this:

Setup:
`#define ADC_PIN ADC1_CHANNEL_4
  adc1_config_width(ADC_WIDTH_12Bit);
  adc1_config_channel_atten(ADC_PIN, ADC_ATTEN_0db);`

and to read the voltage (in mV):
`int voltage_mv = adc1_get_raw(ADC_PIN);`

septatrix, 2022-01-24:
> For the first version of the Picoclick (not the C3 version) I tried to connect the voltage divider to a GPIO on the GND side and turn it low while reading the voltage. Somehow I took a wrong GPIO (probably a floating or a default low one), which was so frustrating that I didn't reconsider working on this again... But now, as it is clear that it was just a wrong chosen GPIO, I will definitely try to implement something like this again! 3µA are still too much...

Isn't a floating pin exactly what you want or more specifically high impedance (the third state apart from input/output)? Output-low would not yield an improvement, output-high would probably either damage the ADC pin when the μC has power or at least be equivalent to output-low without power. Input on the other hand might also damage the controller? Though I am tapping a bit in the dark here as one does not deal with powerless μCs every day and just imagining what might be possible. High impedance should behave as close to an unconnected pin as possible though I am also not sure what voltage the ADC would be exposed to in that scenario.

The safest bet would probably be a transistor with a big pull-down between the voltage divider and GND (as well as maybe also the midpoint and ADC - again no clue what voltage would be there otherwise).The base of the transistor(s) would be connected to an output-low, input or high impedance pin of the ESP32 with a big pull-down in the latter cases to prevent the pin from floating. As such the pd should not draw significant power. It might also be possible to use a single transistor at the high-voltage side of the divider though I am again out of my comfort zone here.

makermoekoe, 2022-01-25:
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

Thank you so much for sharing your thoughts, this is a huge help!

I've just checked the [ESP32 C3 datasheet](https://www.espressif.com/sites/default/files/documentation/esp32-c3_datasheet_en.pdf) and on page 10/11 it seems like every GPIO of that CPU is a high impedance one (marked with a T)?!

I should definitely give it a try on the breadboard. Either this and the transistor solution.

septatrix, 2022-01-25:
> Thank you so much for sharing your thoughts, this is a huge help!
>
> I've just checked the [ESP32 C3 datasheet](https://www.espressif.com/sites/default/files/documentation/esp32-c3_datasheet_en.pdf) and on page 10/11 it seems like every GPIO of that CPU is a high impedance one (marked with a T)?!

Yes they should all be capable of high-impedance though I am not sure which state is active during boot. Maybe the [ESP32-C3 Technical Reference Manual (Section 5.11)](https://www.espressif.com/sites/default/files/documentation/esp32-c3_technical_reference_manual_en.pdf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) if of a bit more help. It talks about the state during reset though I am not sure if this also applies to the powered down state.

> I should definitely give it a try on the breadboard. Either this and the transistor solution.

I think the transistor solution is better. Otherwise if the low side and midpoint of the voltage divider are connected to high impedance pins the whole line should(?) be at the voltage level of the battery which might still damage the pins (https://electronics.stackexchange.com/a/491928).

septatrix, 2022-01-27:
Sadly I do not have the components on hand but maybe the following can help you:

* [Battery Voltage Monitoring (StackExchange)](https://electronics.stackexchange.com/a/424634/306001)
* https://jeelabs.org/2013/05/17/zero-powe-battery-measurement/
* https://jeelabs.org/2013/05/18/zero-power-measurement-part-2/index.html

makermoekoe, 2022-01-27:
Especially the idea behind the third link looks very interesting! Just a short period of time to take the measurement but that should be fine, I like it.

I will give it a try on the weekend and keep you updated!

makermoekoe, 2022-02-03:
Ouuh yes! It works.
This problem finally made me buy an oscilloscope 😄 I received it yesterday and initially tested it with the third point of your list above. It does exactly what it should do. With a 1M pullup resistor to the pmos, I got 196ms where the ADC can be read. With a 100k I got 20ms and so on.

Next I will try to hook it up to the Picoclick completely (the mosfet control was done with a jumper only, but that shouldn't be a problem)

septatrix, 2022-02-04:
Didn't you have one in your video or did you borrow that one? Anyways glad to see that it worked as I have not been able to test it myself.

For everyone who is curious I made a simulation for the [circuit with a transistor](https://www.falstad.com/circuit/circuitjs.html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) as well as for the [circuit with a capacitor](https://www.falstad.com/circuit/circuitjs.html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)
The circuit with a capacitor needs some time to charge the capacitor before a measurement can be taken which the transistor circuit does not require. The transistor circuit also seems to be able to handle floating connections better. Apart from that they should function very similar. It might be interesting to compare the leakage current for both of them. Should you have the components lying around it might be interesting to compare with the Otii Arc ;D

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

septatrix, 2022-04-06:
Hey, just wanted to check in whether you worked on this the last two months? :)

makermoekoe, 2022-04-07:
How time flies 😰
But yes I have worked on it for the last two months! Not sure if you're following on Instagram, but my latest board (the purple Paperclick one) has both the new battery monitoring feature with a single mosfet and the latching circuit with VDD_SPI on board. Second one is already tested and works like a charm! Have to do some scope measurements but so far I haven't got any unsuccessful button presses. Once calling deepsleep the device turns itself off. And the best: if you're not in deepsleep the device will keep its power while flashing, so the button doesn't need to be pressed during the upload.

The battery monitoring will be tested latest on the weekend. I have added a couple of test points to the board in order to make a few measurements. The only thing I can tell you right now is that we're at 120nA "sleep" current (measured with the Power Profiler Kit 2).

In parallel I am working on a C3T v2 :)

septatrix, 2022-04-07:
That's great to hear. Can't wait for a new video :)

Nauman3S, 2022-10-16:
How long the battery could last on a single charge? Maybe one month?

haldi4803, 2022-10-30:
>

Going by the 11 MicroAmps in Deepsleep (with Motion Sensor) and the 30mAh Battery used that would be around 113 Days Deep Sleep only.

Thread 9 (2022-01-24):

Break-out extra pins

cpq, 2022-01-24:
It'd be cool to break out some (minimum 4) extra pins, as pads or as pin holes or as a miniature JST connector

makermoekoe, 2022-01-24:
This is planned for the Picoclick C3, the big brother of the C3T which comes in the same package as the [Picoclick](https://github.com/makermoekoe/Picoclick). The linked, old Picoclick has external pins either.

hallard, 2022-02-15:
yeah +1, an I2C QWIC connector would be perfect :-)

Closed 2022-01-27.

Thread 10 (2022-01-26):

port_common.c:129: undefined reference to `app_main'

Bibbbi, 2022-01-26:
I use ESPRESSIF IDF v4.3.2 for software development. This allows the **Picoclick_C3T_hwtest_v2** example to be compiled successfully.

With **ESPNOW_master** and **Picoclick_ESPNOW_slave** I always get the following error:

``FAILED: ESPNOW_master.elf
cmd.exe /C "cd . && C:\Users\Markus\Documents\esp\.espressif\tools\xtensa-esp32-elf\esp-2021r2-8.4.0\xtensa-esp32-elf\bin\xtensa-esp32-elf-g++.exe  -mlongcalls -Wno-frame-address   @CMakeFiles\ESPNOW_master.elf.rsp  -o ESPNOW_master.elf  && cd ."
c:/users/markus/documents/esp/.espressif/tools/xtensa-esp32-elf/esp-2021r2-8.4.0/xtensa-esp32-elf/bin/../lib/gcc/xtensa-esp32-elf/8.4.0/../../../../xtensa-esp32-elf/bin/ld.exe: esp-idf/freertos/libfreertos.a(port_common.c.obj):(.literal.main_task+0x14): undefined reference to `app_main'
c:/users/markus/documents/esp/.espressif/tools/xtensa-esp32-elf/esp-2021r2-8.4.0/xtensa-esp32-elf/bin/../lib/gcc/xtensa-esp32-elf/8.4.0/../../../../xtensa-esp32-elf/bin/ld.exe: esp-idf/freertos/libfreertos.a(port_common.c.obj): in function `main_task':
C:/Users/Markus/Documents/esp/.espressif/frameworks/esp-idf-v4.3.2/components/freertos/port/port_common.c:129: undefined reference to `app_main'
collect2.exe: error: ld returned 1 exit status
ninja: build stopped: subcommand failed.
ninja failed with exit code 1``

makermoekoe, 2022-01-28:
For the ESP32-C3 you will need to update your esp-idf to v4.4-rc1. Would be nice if you can try this and let us know if this will help.

I've uploaded both examples (espnow slave & master) for building without PlatformIO. May you wanna try this as well.

Bibbbi, 2022-01-29:
The newer [build](https://github.com/makermoekoe/Picoclick-C3/tree/0d348d197d335b6a68c77b21edbe15e7a65e43cf) has fixed the problem. You can close this issue. Thank you.

Closed 2022-01-29.

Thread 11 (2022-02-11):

Pick and Place for PCBway?

Fedack, 2022-02-11:
Greetings!
Considering your store is often out of stock of those, I wanted to know if you'd be willing to add the pick and place for PCBway as one of the files?
I'm sadly not good enough yet in soldering to work with such small components but I could actually use such a small IOT Button.

Thanks,
Fedack

Fedack, 2022-02-11:
I'm stupid, I just noticed they are in the assembly file. Ignore this

makermoekoe, 2022-02-11:
Great you found it. Just to let you know, I've worked on a restock of Picoclicks the last days, which will probably take place on this weekend. Unfortunately I'm not able to provide the amount of boards which are required, meaning they will be sold out again very fast.

Fedack, 2022-02-11:
Well, I joined the wait list for a couple. I saw the cost on pcbway and
since it's such a short run I don't think it's worth spending 200$ cad+ for
5 of the things.

On Fri., Feb. 11, 2022, 7:58 a.m. makermoekoe, ***@***.***>
wrote:

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

Closed 2022-02-11.

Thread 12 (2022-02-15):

Not an issue, just question : USB-C Reference

hallard, 2022-02-15:
Just found. your awesome project, impressive and nice idea.
As you can see on my profile I'm also doing a lot of stuff on ESP32 core and I'm moving now all my boards from Micro USB to USB-C, but I had some issues with some of them so I was wondering if you will able to share reference of your if it works. I'm using eagle also so it could just fit on my board as is.
What MPN or manufacturer reference are you using to order the `USBC_C393939` connector?

Thanks fr your help

hallard, 2022-02-15:
Thanks for the prompt response LSC reference is fine for me since my overseas manufacturer source on them.

Thanks for the mouser link also, sometimes my French manufacturer needs it.

Closed 2022-02-15.

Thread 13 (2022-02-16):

Could this make the total time even shorter?

Fyod, 2022-02-16:
I was browsing around some ESP32 troubleshooting and found this interesting issue over at Espressif's GitHub https://github.com/espressif/esp-idf/pull/5777 but I don't know if this pertains to the C3 as well.

> By calibrating only when necessary, ESP32 wakeup to app_main entry is reduced from 27ms to 17ms; more significantly, ESP32-S2 is reduced from 90ms to 17ms.

Cheers!

makermoekoe, 2022-02-17:
Seems like an easy way to reduce boot up time, but unfortunately I cannot find the file in the esp-idf folder for the ESP32C3.

Nevertheless there is a line in the menuconfig which says "Number of cycles for RTC_SLOW_CLK calibration". Seems like it is almost the same 😄 It is currently set to 1024. I will check the behavior of reducing this value soon!

Fyod, 2022-02-17:
Sweet! Hope it helps. Every millisecond counts 😉

Fyod, 2022-02-18:
Over 10%, not bad! Nearly reaching standard internet ping times, lol.

Slightly related - Is connecting to a wifi AP out of question? It would likely take many seconds?

makermoekoe, 2022-04-25:
We've found a new solution which was discussed [here](https://github.com/espressif/esp-idf/issues/8390).

It uses the VDD_SPI pin of the chip as the latch pin. Once enabling deep sleep of the MCU the chip will shut down the flash to save power, which will shutdown the complete Picoclick as well.

joba-1, 2022-04-25:
Thanks, very clever solution - as long as you have access to that line.
I mostly don't have, and I like that the RC solution seems quite universal and chip independent. Guess I'll try and see if there are drawbacks when I need it.

Closed 2022-04-25.

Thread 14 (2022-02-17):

guidance with software

Zixim, 2022-02-17:
So I just received a batch of 3 Picoclick-C3 devices.
The device is really well made, great job @makermoekoe !!

The thing I'm now stuck with is that I don't see an easy path for integrating the devices into my Home Assistant setup?

- I have many ESPHome-based devices around the house, but that doesn't look like a great option, ESPHome will likely kill the battery life - even with deepsleep.
- MQTT might be an option, but I have zero experience with the Arduino-IDE...
- ... ?

So, is anyone using the Picoclick-C3 with Home Assistant? How?

Failing anyone with Home Assistant experience, what would be the best way to achieve this ?

makermoekoe, 2022-02-17:
Great to hear so, thank you!

Unfortunately I've either not worked with Home Assistant nor with ESPHome yet, but we will somehow get it working. MQTT is probably one of the easiest ways to get it to work, but the Picoclick would get a delay from the button press to sending its message because it has to connect to the router first.

How do you program your ESPHome devices? Is it possible to equip one of these devices with a modified/custom code? Then the best solution would be to act one of those as an ESPNOW master device, which will act as a broker between your Picoclicks and your smart home. In this case you will get an immediate response in your smart home like shown in the Youtube video of the Picoclick.

If this isn't possible you can set up an extra ESP device to be the broker/bridge between the Picoclicks and the smart home.

Zixim, 2022-02-17:
I've been using a few of these : [Hugo-ESP8266](https://github.com/mcer12/Hugo-ESP8266) , they are using MQTT, and I'm very happy with the latency. But they are using a batt with much higher capacity.
No longer available, so I went looking for alternatives & came across Picoclick.

ESPHome compiles a yaml file and offers to upload via OTA, or USB, or download the binary fw and use a flasher software on your computer.
People have been trying to include an ESPNOW component into ESPHome, but it isn't there (yet)... <https://github.com/iphong/esphome-espnow>

"...set up an extra ESP device to be the broker/bridge..." this would certainly be an option, have you got a specific tutorial in mind ?

Zixim, 2022-02-17:
Would you mind sending the bin files for flashing please ?

makermoekoe, 2022-05-25:
I've finally set up my first Home Assistant instance and I'm very pleased by it. So happy about it that I shifted all my smart home devices to work with HA.
In addition to this I started to work with ESPHome as well, which seems to be a very useful tool for non-battery powered devices (haven't played with deep sleep in ESPHome at all). Thus I think integrating the Picoclicks to ESPHome is not the best solution.

Nevertheless I wanted to integrate them to HA so I tried this by using the MQTT plugin. But as I want to use ESPNow for the Picoclicks because it is way faster and extends battery life I set up a ESPNow to MQTT bridge using an ESP32-S2 Thing board from Sparkfun (should be possible with any ESP based board). I published both the Picoclick code and the bridge code a couple days ago.

After installing the MQTT plugin in HA I added this code to the `configuration.yaml ` which will create three entities for the Picoclick device (battery voltage, battery percentage and binary_sensor):

`sensor:
  - platform: mqtt
    name: Battery_Picoclick1
    state_topic: "home/node1234/battery"
    device_class: voltage
    unit_of_measurement: "V"
    value_template: "{{ value | round(0)}}"
  - platform: mqtt
    name: BatteryLevel_Picoclick1
    state_topic: "home/node1234/batterylevel"
    device_class: battery
    unit_of_measurement: "%"
    value_template: "{{ value | round(0)}}"

binary_sensor:
  - platform: mqtt
    name: Picoclick1
    state_topic: "home/node1234/value"
    payload_on: true
    payload_off: false
    value_template: "{{ value | int > 0 }}"`

All in all this is working brilliant. It is running a couple days now without any problems or interruptions. You won't even notice a delay between pressing the Picoclick and the actuation in HA.

Btw. you don't even have to create entities for the Picoclick, you can use it within the automations of HA directly (via MQTT) which will looks like this for toggling an outlet:

`alias: Picoclick1_automation
description: ''
trigger:
  - platform: mqtt
    topic: home/node1234/value
    payload: '1.00'
condition: []
action:
  - type: toggle
    device_id: YOUR_DEVICE_ID
    entity_id: YOUR_ENTITY_ID
    domain: switch
mode: single`

Hope this helps. If you have questions then please let me know! I'm now on the road to become a HA pro 😄

Zixim, 2022-07-12:
I'd like to know exactly what firmware you are flashing ?

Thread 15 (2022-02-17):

Improve reference designators and orientation of U2

poysh, 2022-02-17:
I managed to assemble the top part of the PCB today with some minor hiccups. Please don't pay too much attention to the solder joints. All components are sourced from Digikey and Mouser with some replacements for parts which were not available.
The hardest part was finding the reference designators on the board drawing and the only workaround was loading the board file into an online viewer and trying to match it. A graphic with good readable reference designators would be a huge help.

Another small problem was trying to find the right orientation of U2 as I couldn't find a dot on the PCB to match the component. After checking the documention of the component and the schematics I was able to narrow it down.

I can try to update the footprint after getting familiar with Eagle and commit a merge request if that helps you.

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

makermoekoe, 2022-04-25:
Great work! Glad somebody tries to solder it himself.
Sorry for the bad labeling, it is fixed now.

Closed 2022-04-25.

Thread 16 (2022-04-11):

Battery discharge at boot?

gnistregn, 2022-04-11:
How come the low discharge rate of such a small battery doesn't cause a brownout when it draws 200+ mA at boot?

Fyod, 2022-04-12:
When I looked into this, I found someone who tested 2x and 3x discharge rate of small cells. It still works, but may affect overall battery life, though not significantly. The discharge rates that manufacturers (brand names like Panasonic) guarantee are best practice that ensures long life.
I don't think voltage sag will be an issue here. it can of course be mitigated with capacitors.

Closed 2023-01-09.

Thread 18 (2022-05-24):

Antenna impedance matching: F2 unknown

fgardt, 2022-05-24:
The part named F2 in schematic and BOM has a value of 0. What would be the correct value here?

(also: since I can‘t find any info on this anywhere, do you know the impedance of the ESP32-C3 itself?)

fg89o, 2022-06-24:
May be i am wrong, but i think is a 0 ohm resistor.

makermoekoe, 2023-01-09:
F2 is just a bridge (0Ohm resistor), and for the C3T there isn't any matching network and impedance matching done. The C3 includes a PI-network and is properly tuned.

Closed 2023-01-09.

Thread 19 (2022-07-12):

how to flash this with ESPHome ?

Zixim, 2022-07-12:
So...I bought 3 pcs a couple of months ago...and I managed to brick 2 of them trying to flash ESPHome onto them.

After flashing serial log (Termite) shows :
```
Using 'COM11' as serial port.
Connecting...
Detecting chip type... ESP32-C3
Connecting...

Chip Info:
 - Chip Family: ESP32
 - Chip Model: ESP32-C3 (revision 3)
 - Number of Cores: 1
 - Max CPU Frequenc... (96 %)Writing at 0x000b8e68... (100 %)Wrote 709504 bytes (420762 compressed) at 0x00010000 in 9.8 seconds (effective 578.8 kbit/s)...
Hash of data verified.

Leaving...
Hard Resetting...
Hard resetting via RTS pin...
Done! Flashing is complete!

Showing logs:
[10:33:43]invalid header: 0xffffffff
[10:33:43]invalid header: 0xffffffff
[10:33:43]invalid header: 0xffffffff
[10:33:43]invalid header: 0xffffffff
...line repeats hundreds of times...
[10:33:44]invalid header: 0xffffffff
[10:33:44]invalid header: 0xffffffff
[10:33:44]invalid header:ESP-ROM:esp32c3-api1-20210207
[10:33:44]Build:Feb  7 2021
[10:33:44]rst:0x7 (TG0WDT_SYS_RST),boot:0xf (SPI_FAST_FLASH_BOOT)
[10:33:44]Saved PC:0x4004c0dc
[10:33:44]invalid header: 0xffffffff
[10:33:44]invalid header: 0xffffffff
[10:33:44]invalid header: 0xffffffff
...line repeats hundreds of times...
```

What is going on ?
Perhaps someone could post a detailed step-by-step ?

makermoekoe, 2022-07-12:
What do mean with brick to of the Picoclicks? How do they behave now?

Regarding ESPHome, may the configuration file for the device could help here. How do you want to integrate them to ESPHome? Via MQTT? I'm still not an ESPHome professional...

TechOverflow, 2022-07-12:
I had the same problem with a few new C3's, albeit programmed via Arduino IDE.
I believe the problem was that I was accidentally pulling up GPIO9 (boot).

Zixim, 2022-07-12:
brick as in impossible to flash anything into them. Well...1 of them keeps rebooting so the comm port disappears in Windows.
If I get the timing right, it does accept a flash.

This is the basic ESPHome conf that I'm trying to run on the PicoClick C3:
```yaml
esphome:
  name: c3

esp32:
  board: esp32-c3-devkitm-1
  framework:
    type: esp-idf

# Enable logging
logger:

# Enable Home Assistant API
api:

ota:

wifi:
  ssid: !secret wifi_ssid
  password: !secret wifi_password

  # Enable fallback hotspot in case wifi connection fails
  ap:
    ssid: "C3 Fallback Hotspot"
    password: "eHc3ejhcDMMy"
```
It flashes OK, but just does this :
```
Using 'COM11' as serial port.
Connecting...
Detecting chip type... ESP32-C3
Connecting...

Chip Info:
 - Chip Family: ESP32
 - Chip Model: ESP32-C3 (revision 3)
 - Number of Cores: 1
 - Max CPU Frequenc... (96 %)Writing at 0x000b8e68... (100 %)Wrote 709504 bytes (420762 compressed) at 0x00010000 in 9.8 seconds (effective 578.8 kbit/s)...
Hash of data verified.

Leaving...
Hard Resetting...
Hard resetting via RTS pin...
Done! Flashing is complete!

Showing logs:
[10:33:43]invalid header: 0xffffffff
400 repeats....
[10:33:43]invalid header: 0xffffffff
[10:33:44]invalid header:ESP-ROM:esp32c3-api1-20210207
[10:33:44]Build:Feb  7 2021
[10:33:44]rst:0x7 (TG0WDT_SYS_RST),boot:0xf (SPI_FAST_FLASH_BOOT)
[10:33:44]Saved PC:0x4004c0dc
[10:33:44]invalid header: 0xffffffff
...repeats...
```

makermoekoe, 2022-07-12:
> I had the same problem with a few new C3's, albeit programmed via Arduino IDE.
> I believe the problem was that I was accidentally pulling up GPIO9 (boot).

That is indeed a problem. What was the reason of pulling it up? I'm asking because it isn't connected to anything...

If you have experience in soldering you can fix it by soldering a jumper cable to pin 15 of the ESP32C3 chip itself. Maybe you can try it without soldering as well, but you have to pull GPIO9 low while the Picoclick boots up, which can be done with pressing a GND connection cable to pin 15 while pressing the button.

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

makermoekoe, 2022-07-12:
> This is the basic ESPHome conf that I'm trying to run on the PicoClick C3:

Then you probably don't toggle the latch and the Picoclick looses power with releasing the button... What about keeping the button pressed? What does happen?

Zixim, 2022-07-12:
Please does anyone have a working basic ESPHome binary, that includes `ap` (without password) and `captive-portal`?
This would allow me to flash any other ESPHome fw into the device.

Zixim, 2022-07-12:
Pulling pin15 (GPIO9) to GND allowed ESPHome to flash the firmware from dashboard.

Boot time is way too long so LDO fails to latch.
I've been trying to set CONFIG_BOOTLOADER_SKIP_VALIDATE_ON_POWER_ON , but don't think that ESPHome has a mechanism for this.

e-noyau, 2022-10-07:
Came here because I just soldered a LiPo to a picoClick C3T I just pulled out of its sealed package and I was going to flash it with ESPHome.  But I don't see any sign of life from the device when I plug it in (No lights, no com port), this is with the button firmly pressed of course (With a clothespin!).

Should I wait for the battery to charge? Anything should be visible while the battery is charging?

Is flashing with ESPHome a bad idea? @Zixim did you manage to get it to work?

Zixim, 2022-10-08:
> Is flashing with ESPHome a bad idea? @Zixim did you manage to get it to work?

bad idea unfortunately.
I did get it to work, but the latency with esphome is wayyyyyy too high when pressing the button.

scottcopus, 2023-01-25:
@Zixim ESPHome _does_ have some deep sleep capabilities of its own. But I've never experimented with it yet to find out its latency. But I'm guessing it'll be longer compared to @makermoekoe's sketch source that's here in the Picoclick's repo.

BTW, @makermoekoe I'd love to see some USA sources for the Picoclick and maybe other devices, and options that include a battery & case... and maybe qty discounts, lol.  Keep up the great work!

Zixim, 2023-01-26:
@scottcopus I have extensively tested ESPHome with deepsleep, and have many battery-powered esp32 devices around the house. They are just about all sensors gathering data (temp, hum, etc...). Latency isn't an issue in that scenario.

When the sleeping device is a controller (buttons to control lights for instance) then anything above 1 or 2 seconds of latency is huge.

ESPHome simply doesn't give us access to the functions in the framework that allow us to reduce startup time.

scottcopus, 2023-01-26:
@Zixim Good to know you've done deepsleep and startup latency testing with ESPHome. I'm sad it's not already optimized. Maybe they'll eventually have those similar menuconfig compile-time optimizations that makermoekoe showed us in one of his YT videos to speed up the boot time. If there's not already an issue within that project to help with this, maybe one of you guys could post it? I wouldn't exactly know how to phrase it.

makermoekoe, 2023-01-27:
> @scottcopus I have extensively tested ESPHome with deepsleep

But not especially for the Picoclick I think? Using deepsleep on the Picoclicks is not possible. At least it cannot wake up from deepsleep, because once the devices enter deepsleep the latch will be pulled low, which deactivates the complete Picoclick (both for the C3 and C3T). A button press is necessary to activate them again.

> @Zixim Good to know you've done deepsleep and startup latency testing with ESPHome. I'm sad it's not already optimized. Maybe they'll eventually have those similar menuconfig compile-time optimizations that makermoekoe showed us in one of his YT videos to speed up the boot time.

The latency of 1 or 2 seconds is not related to the boot-up time, but the WiFi connection process. In my videos I'm using ESP-NOW to communicate with other devices, or moreover an espnow-2-mqtt bridge which will forward the messages from the Picoclicks as MQTT messages (which can be handled from HA). With using espnow the wifi connection is not needed and thus the communication only takes under 200ms (from Picoclick button press to receiving the message on the other side).
If you haven't done yet, watch the last 2-3 mins of my new Youtube video where I show how to do it with the bridge.

Zixim, 2023-01-27:
"But not especially for the Picoclick I think?"
I did try to get ESPHome + deepsleep working on the Picoclick, but - as you say - this is impossible due to latency.

When I say latency, I mean the time that elapses from click to boot to wifi connect to mqtt message transmit. The latch gets pulled low before wifi connects. (Which is a great thing for the battery ofcourse)
ESPHome just isn't the right firmware for the Picoclick.

I did have a look at ESP-NOW, but am reluctant to spin up yet another system in the household, and the setup doesn't look very simple to me.

makermoekoe, 2023-01-27:
> When I say latency, I mean the time that elapses from click to boot to wifi connect to mqtt message transmit. The latch gets pulled low before wifi connects.

But if you pressed the button for around 200ms the Picoclick stays on and then the main latency is due to the wifi connect. The boot-up time is the part between pressing the button and pulling the latch high. After the latch is high the power will stay on.

makermoekoe, 2023-01-27:
> I did have a look at ESP-NOW, but am reluctant to spin up yet another system in the household, and the setup doesn't look very simple to me.

Up to you... It is simply uploading the ESPNOW2MQTT bridge code from the [Picoclick Gitbook](https://makermoekoe.gitbook.io/picoclick-c3/software/esp-now) (with your credentials) to any ESP, take the sender sketch for the Picoclicks and add a new MQTT device in HA. For me it couldn't be simpler at all.

Zixim, 2023-01-27:
here's me adding this to the give-it-a-go list.

Closed 2023-01-27.

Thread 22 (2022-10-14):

Schematics missing for Picoclick C3

septatrix, 2022-10-14:
I just finished watched the YouTube video and came to check for the schematics. However they do not seem to be pushed yet.

Can you tell when we can expect to see them?

WoodwindHu, 2022-10-17:
Same question

janausis, 2022-12-03:
Is there an update on if or when the Schematics will be added?

Ponti17, 2022-12-20:
Also interested in this.

ehsanul, 2022-12-26:
The Gerber files may be downloaded here (requires registration): https://www.pcbway.com/project/shareproject/Picoclick_C3_most_advanced_IOT_Button_98eb1819.html

makermoekoe, 2023-01-09:
Added

Closed 2023-01-09.

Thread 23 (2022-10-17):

Capacitors

mado89, 2022-10-17:
Hi,
thanks for sharing this great project. Some sources recommend quit large capacitors (>1000uF) for applications with WiFi & BLE in order to prevent "random" reboots and similar errors. Have you experienced any issues with your board, i.e. wouldn't it make sense to add bigger capacitors (sacrificing some of the small footprint)?
Thanks!

Closed 2023-01-09.

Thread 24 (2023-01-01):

How large is the signal range

septatrix, 2023-01-01:
I cannot find a proper antenna or any matching circuit in the schematics and/or picture at all so was wondering how good the range on these devices will be (both the C3 and the C3T)?

tregota, 2024-01-02:
While this hasn't been answered in a year, I still would like to add to the question. I have seen others using ESP-NOW that enable long range mode with `esp_wifi_set_protocol(WIFI_IF_STA , WIFI_PROTOCOL_LR)` but you do not use this in your example code. have you tried it and rejected it or not tried it? Is it perhaps more power consuming?

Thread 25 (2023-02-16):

Battery monitoring Mosfet

MukeshKumarRattu, 2023-02-16:
The direction of the battery monitoring mosfet it seems like not good. The current flow is in opposite direction so how the controller get the value ?

makermoekoe, 2023-02-28:
Check this one: https://github.com/makermoekoe/Picoclick-C3/issues/8

Closed 2023-02-28.

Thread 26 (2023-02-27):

Value for capacitor C5 on the Picoclick c3

piningforfjords, 2023-02-27:
I noticed there is no value for the capacitor C5.  Was this something you were tweaking for the antenna?  Did you find a good value?

makermoekoe, 2023-02-28:
Actually 0Ohm works great. But haven't measured for any better solutions...

piningforfjords, 2023-03-01:
Ahh thanks for getting back to me.  I noticed you saying that in a comment  somewhere.  I didn't put it together because his is marked as a cap.  I won't make another issue that C5 should be marked as a resistor but someone might later.  I greatly admire your work.

chrisnet123, 2023-09-06:
Looking at picoclick_c3_v1.1.pdf C5 has no value. Is this a capacitor or a resistor? What is its value? Thanks! I love the board design and can not wait to adjust it!

makermoekoe, 2023-09-07:
Sorry, C5 is a part of the PI-matching network of the antenna. But for this board C5 should not be mounted. The other two components of the network are enough.

@piningforfjords I thought you are talking about the C3T where the antenna needs a 0ohm resistor in series, but for the C3 the parallel capacitor C5 should not be placed.

chrisnet123, 2023-09-07:
Thanks for the clarification. For the Picoclick C3  "C5" does not get placed! so it only needs C17 and C18. If I look at https://github.com/makermoekoe/Picoclick-C3/blob/main/docs/pc3_production.jpg and zoom in, I see it is not placed..... Thanks.

Closed 2023-02-28.

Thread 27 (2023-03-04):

General questions about ESP32-C3

windorey, 2023-03-04:
Hello, sorry to bother but I am making my own ESP32-C3 board and now I am concerned about one thing.
Can I flash the board via USB by just connecting my USB connector to GPIO 18 and 19? Do I need to hold some pin high or low to upload specifically? Thanks in advance for any reply.

TechOverflow, 2023-03-04:
You don't normally need boot or reset to flash the binary via USB.
The issue I find is that for some reason, the C3 chips show a header error from the factory. This means that for the very first flash, you need to hold boot low before powering up (before plugging in USB) to boot into "upload mode". So you definitely want to have the option to short IO9 (boot) and EN (reset) to ground. On most ESP boards, this is done with buttons, but personally, since boot/reset are virtually never needed (especially if you intend on flashing OTA) I just place pads on the board so that I can short them with tweezers or something, instead of having to place actual buttons on the board.

windorey, 2023-03-04:
Does this also apply for ESP32-S3?

TechOverflow, 2023-03-04:
I have not had any projects with S3 modules, only S3 dev board, but I can imagine it's similar. Just make sure to check the datasheet for which IOs are strapping pins. For example on ESP32-C3 boot is IO9 to gnd, on ESP32 (original) boot is IO0, on ESP32-S3 boot is also IO0. Reset is always CHIP_PU (aka EN).
Best to check the schematics for one of the dev boards.

windorey, 2023-03-04:
Thank you. Also, for the ESP32 series, what are the XTAL pins, what I need to connect to them, and how do i find the value of what I need to connect to them?

NilsBe, 2023-03-05:
See page 15 of the esp32-c3 datasheet:

https://www.espressif.com/sites/default/files/documentation/esp32-c3_datasheet_en.pdf

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

NilsBe, 2023-03-05:
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

> Hello, sorry to bother but I am making my own ESP32-C3 board and now I am concerned about one thing. Can I flash the board via USB by just connecting my USB connector to GPIO 18 and 19? Do I need to hold some pin high or low to upload specifically? Thanks in advance for any reply.

See page 15 of the esp32-c3 datasheet:

https://www.espressif.com/sites/default/files/documentation/esp32-c3_datasheet_en.pdf

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

NilsBe, 2023-03-05:
> Hello, sorry to bother but I am making my own ESP32-C3 board and now I am concerned about one thing. Can I flash the board via USB by just connecting my USB connector to GPIO 18 and 19? Do I need to hold some pin high or low to upload specifically? Thanks in advance for any reply.

See page 15 of the esp32-c3 datasheet:

https://www.espressif.com/sites/default/files/documentation/esp32-c3_datasheet_en.pdf

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

makermoekoe, 2023-03-06:
> Can I flash the board via USB by just connecting my USB connector to GPIO 18 and 19? Do I need to hold some pin high or low to upload specifically? Thanks in advance for any reply.

Short answer: Yes, it is as easy as connecting those pins directly to the use connector. For me, even the boot strapping pin (for the C3 it is GPIO9) doesn't held to be low while uploading for the first time. If there's an header error incoming, you can solve it but just trying a second upload, which worked in almost every situation for me.
As @NilsBe mentioned, GPIO2 and GPIO8 should always be pulled up externally.

> Does this also apply for ESP32-S3?

For my S3 projects, I always put Boot and Reset buttons on the board. When entering the download mode another USB port will be opened (it is a real USB CDC port on the MCU side). Automatic download entering is (compared to the C3 and as far as I now) not possible for the S3 (and S2 either).

windorey, 2023-03-06:
I noticed the ESP chips need an external crystal and antenna, how to pick the right ones? I'm so sorry for asking so many questions.

makermoekoe, 2023-03-06:
Yes, the bare chips need both of them. But if you're not familiar with that it maybe is best to go with a module where everything is included. Modules with the ESP32-C3 are the ESP-C3-Mini-1 or the ESP32-C3-WROOM-02 just for example.

Else you need both crystal and antenna as the datasheet says. I'm using a 40MHz 2016 crystal with 9pF load capacitors and any 2.4GHz antenna with matching network according to your PCB layout. Currently using the SLDA31 or the PROANT440 3D antenna.

TechOverflow, 2023-03-06:
> 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

Interestingly though, Espressif do not pull GPIO2 high in any of their C3 Dev boards.

windorey, 2023-03-06:
I notice a board "ESP32-PICO-KIT" has some "3D Antenna", I want to use it on my board. How can I find the part and use it in my schematic?

makermoekoe, 2023-03-06:
Yes, that one is the Abracon Pro-Ob-440 which I have mentioned above. Just create it on your own according to the datasheet, these are just four pads of which only two are connected. But it seems like there is also an ecad model on [Mouser].(https://www.mouser.de/ProductDetail/ABRACON/PRO-OB-440?qs=TCDPyi3sCW1HMjuU5AeiSw%3D%3D)

Closed 2023-03-06.

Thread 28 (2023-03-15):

ESPHome try again C3

mnestor, 2023-03-15:
I saw the previous issue #19 and decided to try this anyway. I don't need crazy fast as for this one I just want it as an easy button to log when medication is taken.

It works perfectly if I solder the usb jumper and power it that way. But when I put the battery on I need to hold the button for a second. From what I've read I guess I need to be pulling up a pin?

```yaml
esphome:
  name: c3-sonia-pill
  platform: ESP32
  board: esp32-c3-devkitm-1
  # on_boot:
  #   priority: 400
  #   then:
  #     - light.turn_on:
  #         id: ledClk
  #         color_mode: RGB
  #         brightness: 100%
  #         green: 100%

substitutions:
  use_address: !secret ip_pc_01
  name: pc01
  ip: !secret ip_pc_01

mqtt:
  broker: 10.5.10.100
  username: picoclick
  password: !secret mqtt_pass_pc
  on_connect:
    then:
      - binary_sensor.template.publish:
          id: resetPill
          state: ON
      - delay: 5s
      - binary_sensor.template.publish:
          id: resetPill
          state: OFF
      - light.turn_on:
          id: ledClk
          color_mode: RGB
          brightness: 100%
          red: 100%
          green: 0
      # - deep_sleep.enter: deepSleep

# <<: !include common/api.yaml
<<: !include common/wifi.yaml
<<: !include common/ota.yaml

# Enable logging
logger:

deep_sleep:
  id: deepSleep
  run_duration: 30s

# light:
#   - platform: fastled_spi
#     chipset: APA102
#     data_pin: GPIO7
#     clock_pin: GPIO6
#     num_leds: 2
#     rgb_order: BGR
#     name: "Picoclick state"
#     id: ledClk

sensor:

  # update this to do a sampling and average
  - platform: adc
    pin: 4
    name: "Sonia Pill Button Voltage"
    update_interval: 60s
    filters:
      - lambda: return x * 1.43 + 0;

binary_sensor:
  - platform: gpio
    pin: 5
    name: "Sonia Pill Button"
    on_release:
      - deep_sleep.enter: deepSleep
    on_press:
      - deep_sleep.prevent: deepSleep

  - platform: template
    name: "Reset Pill"
    id: resetPill
```

mnestor, 2023-03-15:
I figured it out, I was reading the arduino code wrong and trying to pull up the wrong pin...

Here is a working ESPHome setup for anyone that might want it. It just starts up, toggles a binary in mqtt that home assistant triggers an automation off of. Takes 2-6 seconds depending on interference in your wifi it seems.

```
esphome:
  name: c3-sonia-pill
  libraries:
    # this overrides the built in version 3.3.2
    # needed for this to compile
    - FastLED=https://github.com/FastLED/FastLED.git#3.5.0
  on_boot:
    # earliest possible time
    priority: 700
    then:
      # pull the pin up so we stay on
      - output.turn_on: my_pin
      # turn on a light so we know we're working
      - light.turn_on:
          id: ledClk1
          brightness: 100%
          red: 0
          green: 0
          blue: 100%

esp32:
  board: esp32-c3-devkitm-1
  variant: ESP32C3

substitutions:
  use_address: !secret ip_pc_01
  name: pc01
  ip: !secret ip_pc_01

mqtt:
  broker: 10.5.10.100
  username: picoclick
  password: !secret mqtt_pass_pc
  on_connect:
    then:
      # when we connect to mqtt turn on a red light
      - light.turn_on:
          id: ledClk2
          brightness: 100%
          red: 100%
          green: 0
          blue: 0
      # publish something to mqtt so home assistant
      # can create an automation around it
      - binary_sensor.template.publish:
          id: resetPill
          state: ON
      # since we did that turn the red light green
      - light.turn_on:
          id: ledClk2
          brightness: 100%
          red: 0
          green: 100%
          blue: 0
      # give a slight delay then get out of dodge
      - delay: 1s
      - binary_sensor.template.publish:
          id: resetPill
          state: OFF
      # going to sleep now
      - deep_sleep.enter: deepSleep

<<: !include common/wifi.yaml
<<: !include common/ota.yaml

# Enable logging
logger:

deep_sleep:
  id: deepSleep
  run_duration: 30s

light:
  # create the fastled spi light
  - platform: fastled_spi
    name: "Picoclick state"
    num_leds: 2
    rgb_order: BGR
    chipset: APA102
    data_pin: GPIO7
    clock_pin: GPIO6
    id: ledClk
  # break up the 2 leds
  # this is kinda working? i need more debugging
  - platform: partition
    id: ledClk1
    segments:
      - id: ledClk
        from: 0
        to: 0
  - platform: partition
    id: ledClk2
    segments:
      - id: ledClk
        from: 1
        to: 1

sensor:
  # TODO: update this to do a sampling and average
  - platform: adc
    pin: 4
    name: "Sonia Pill Button Voltage"
    # long update time so we only do this once
    update_interval: 60s
    filters:
      - lambda: return x * 1.43 + 0;

binary_sensor:
  # this is so we can hold the button and prevent sleep
  - platform: gpio
    pin: 5
    name: "Sonia Pill Button"
    on_release:
      - deep_sleep.enter: deepSleep
    on_press:
      - deep_sleep.prevent: deepSleep

  - platform: template
    name: "Reset Pill"
    id: resetPill

# how we keep the picoclick awake at the start
# this will pull high in the on_boot
output:
  - platform: gpio
    pin: 3
    id: my_pin
```

Closed 2023-03-15.

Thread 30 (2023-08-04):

Missing Eagle Libraries and BOM not complete

minkione, 2023-08-04:
Hi, I noticed two things while opening the project in Eagle:
1) There are some ad-hoc libraries missing for Eagle.
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

2) The BOM doesn't have the precise manufacturer codes of the components and is harder to find the exact components on Digikey or LCSC.
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

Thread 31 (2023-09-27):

C3 BOM and incomplete GitBook

janausis, 2023-09-27:
Hey, am I just blind or where is the full BOM of the C3? I know there kinda is one for main components, but none for smaller ones. Also a lot of Info for actually building it seems to be missing from the Gitbook. It's not impossible, but I would love for some additional information.

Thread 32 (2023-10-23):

Add second button to schematic, with same wakeup function

AshwinDeTaeye, 2023-10-23:
Hello,

I would like to add a second button to the schematic.
If possible have the same wake-up functionality as the first button.
Do I need to duplicate the below schematic completely for a second button?

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

makermoekoe, 2023-10-30:
Hey, you don't have to copy the whole circuit part. What's necessary for a second button are these components: SW1, R10, C19, R14 and D3. D3 is a dual diode, but you will only need one of them. The anode of the diode will be connected to the EN_LDO line.

AshwinDeTaeye, 2023-11-07:
Hello, thanks. Just to be sure could you check the modified schematics?

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

Closed 2023-10-30.

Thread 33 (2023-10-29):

Picoclick C3 not recognized in Windows 11?

tregota, 2023-10-29:
Do I need a driver for the picoclick to show up in PlatformIO win Windows11?
I have tried a variety of cables, the picoclick lights up but nothing shows up in platformio or in the device manager.

makermoekoe, 2023-10-30:
It's probably only the charge status LED which lights up. Do you have a suitable power supply connected to the battery port? A Lipo battery or something between 3.6V and 4.2V is perfect.
If you don't wanna use an external power supply, you have to short a soldering jumper on the device: https://makermoekoe.gitbook.io/picoclick-c3/hardware

tregota, 2023-10-30:
Ah, sorry, I was not aware of this. Seems I made assumptions when I should have been rtfm. :)
I'll try again with a battery soldered to it. Thanks.

Closed 2023-10-30.

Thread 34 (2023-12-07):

Add second button to schematic, with same wakeup function

AshwinDeTaeye, 2023-12-07:
If i would add a second button, would this be correct:

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

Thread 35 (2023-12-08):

flashing with Arduino IDE over native USB

nuri2408, 2023-12-08:
Hello,
I've built an similar picoclick based on yours. I want to flash some Arduino Sketch over the native USB (gpio 18/19). Flashing with an external USB/Serial converter works great, but with Native USB windows say that the device was not recognized properly and not Port is showing up. What am I doing wrong?
Thanks!

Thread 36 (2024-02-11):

BUTTON Input gets too high Voltage on the ESP32 when running a full charged Li Ion Battery with 4.2 V

frsoeteb, 2024-02-11:
Hi, according to the schematic the BUTTON line could get ~3.8V when pressing the on board button, which would be more than the Max Input Voltage specified for the ESP32 as VDD+0.3 V which would mean 3.6V in this case. Did you run into any problems with this setup so far?

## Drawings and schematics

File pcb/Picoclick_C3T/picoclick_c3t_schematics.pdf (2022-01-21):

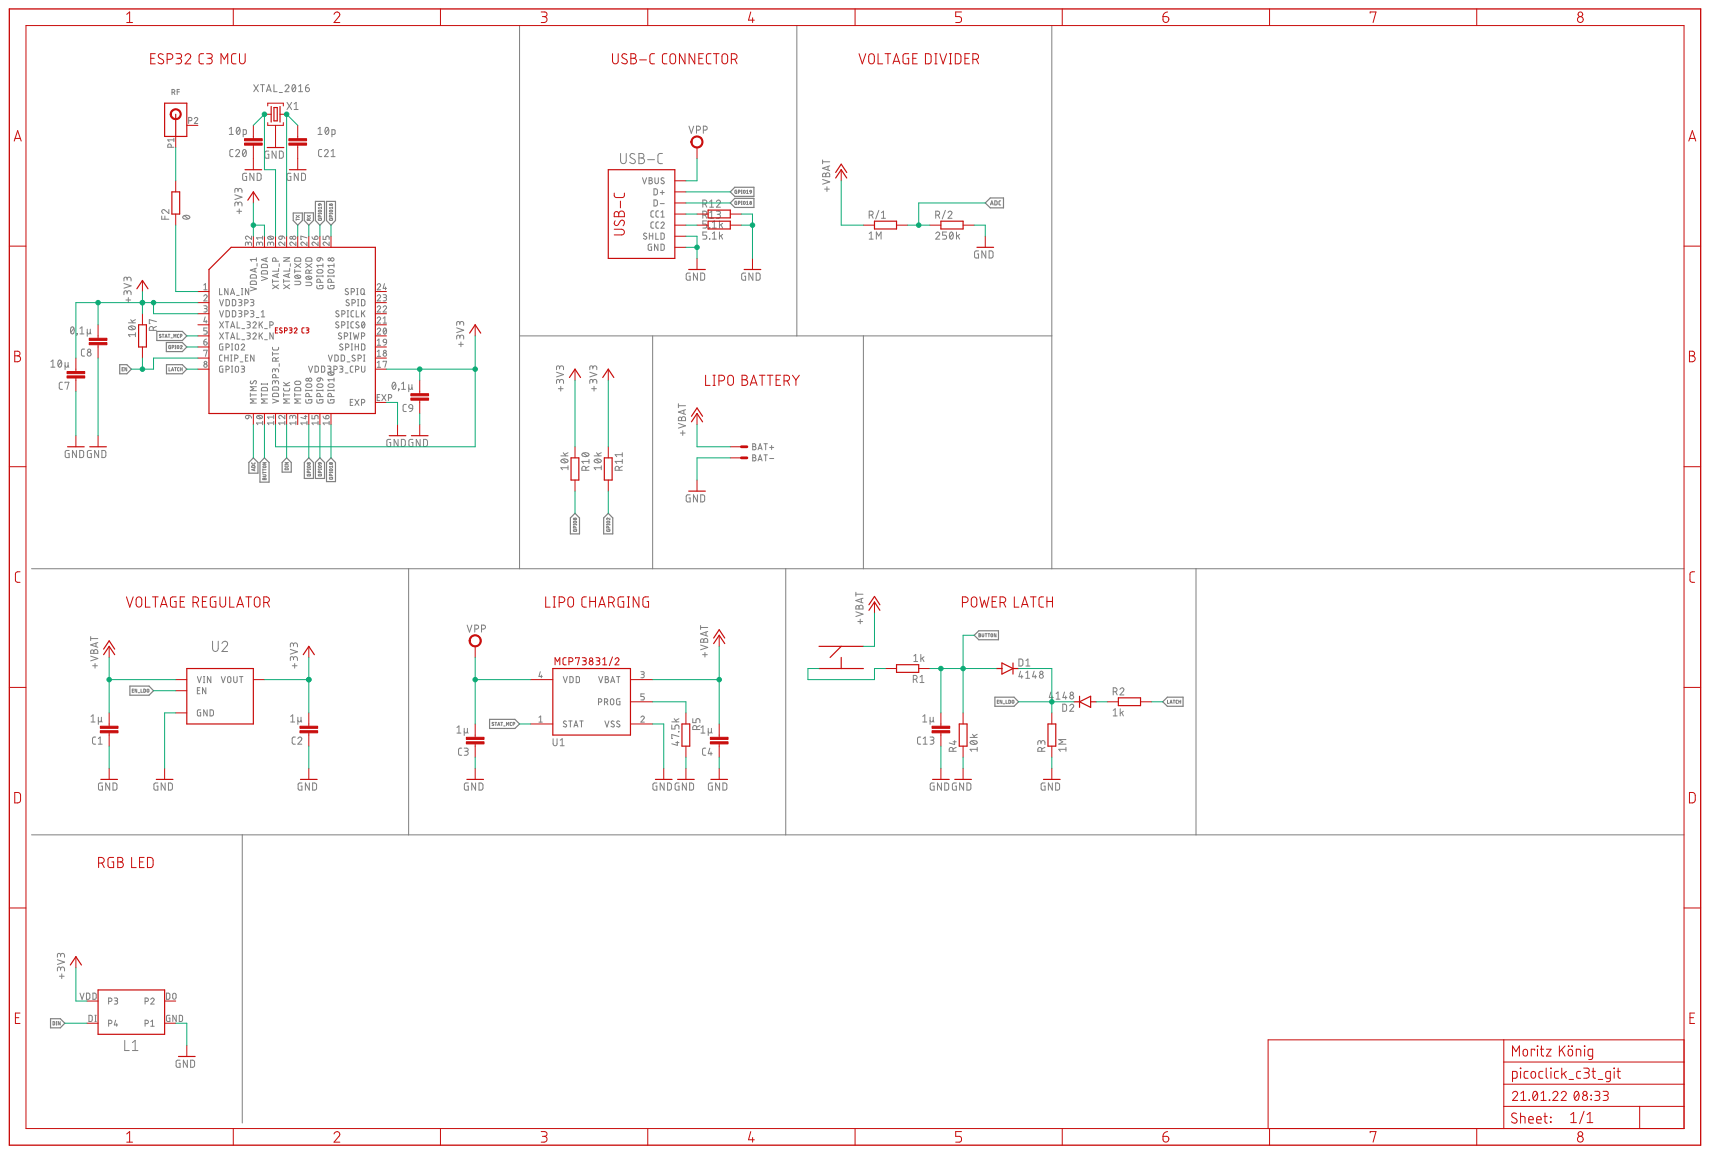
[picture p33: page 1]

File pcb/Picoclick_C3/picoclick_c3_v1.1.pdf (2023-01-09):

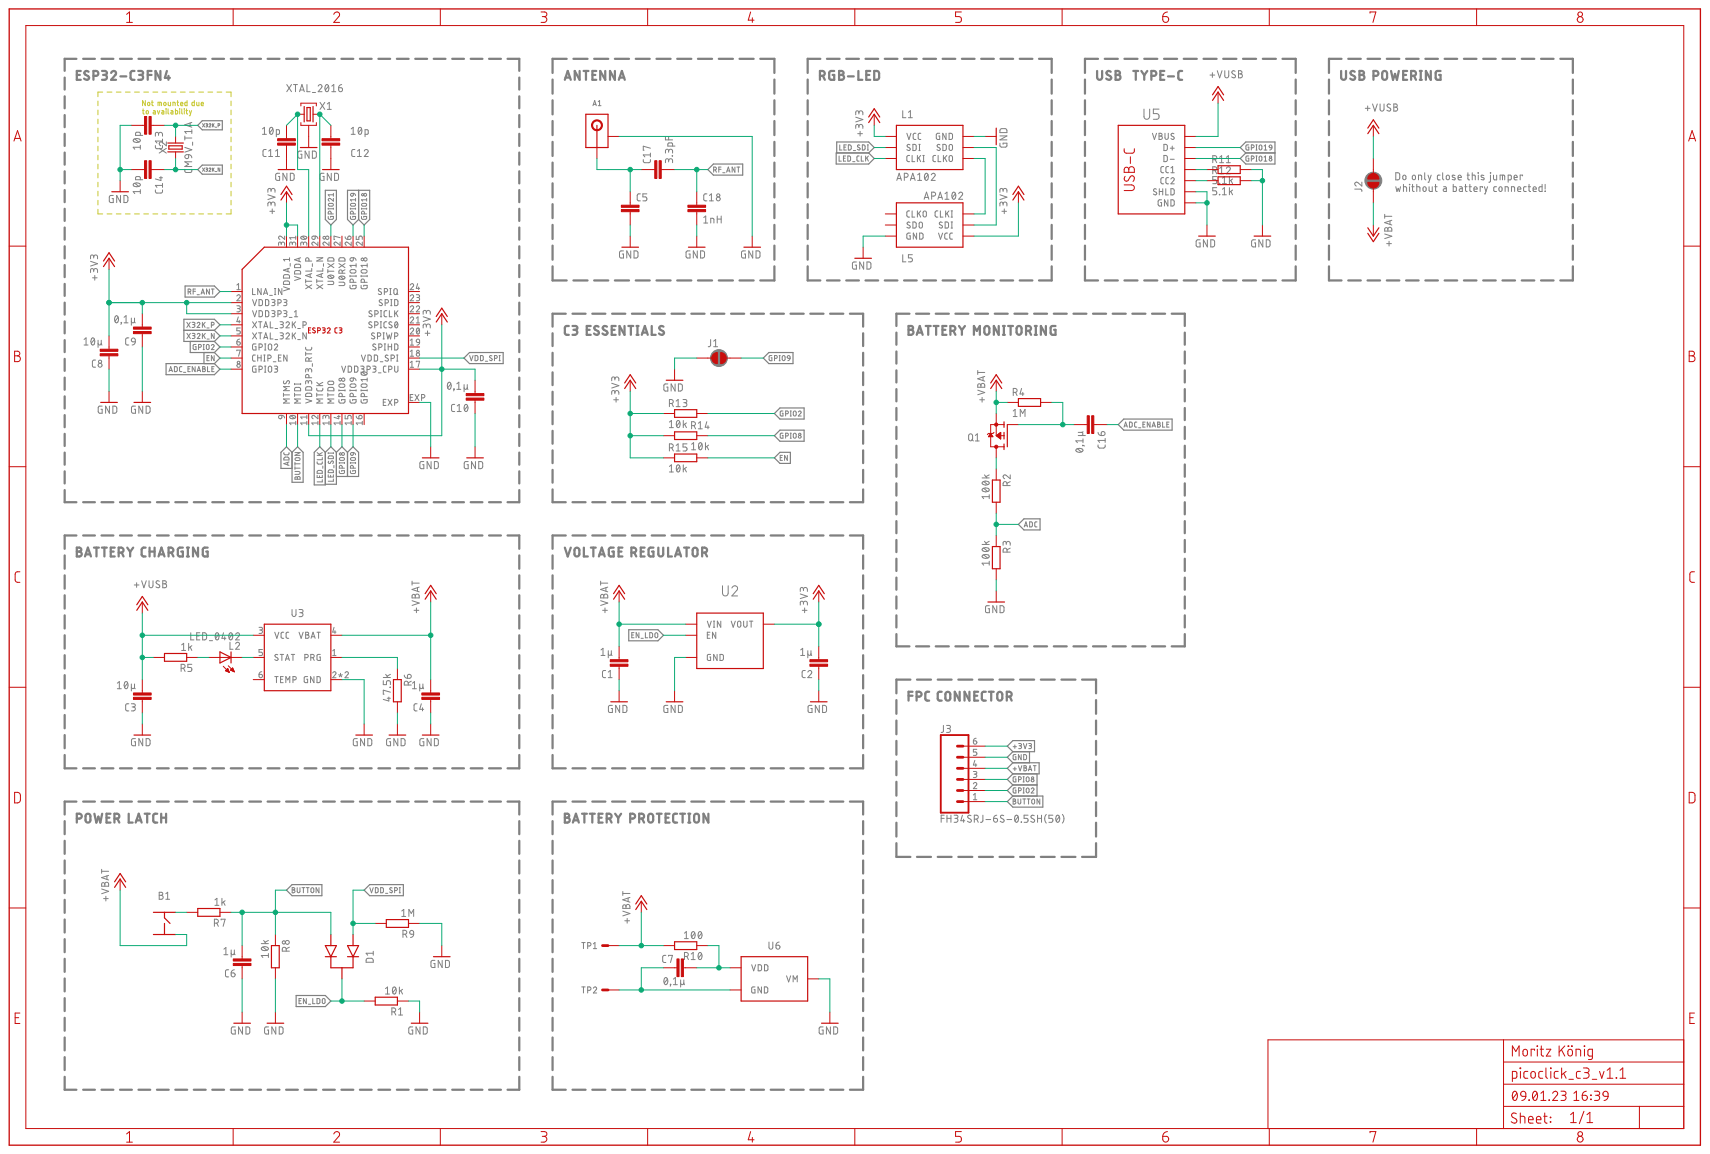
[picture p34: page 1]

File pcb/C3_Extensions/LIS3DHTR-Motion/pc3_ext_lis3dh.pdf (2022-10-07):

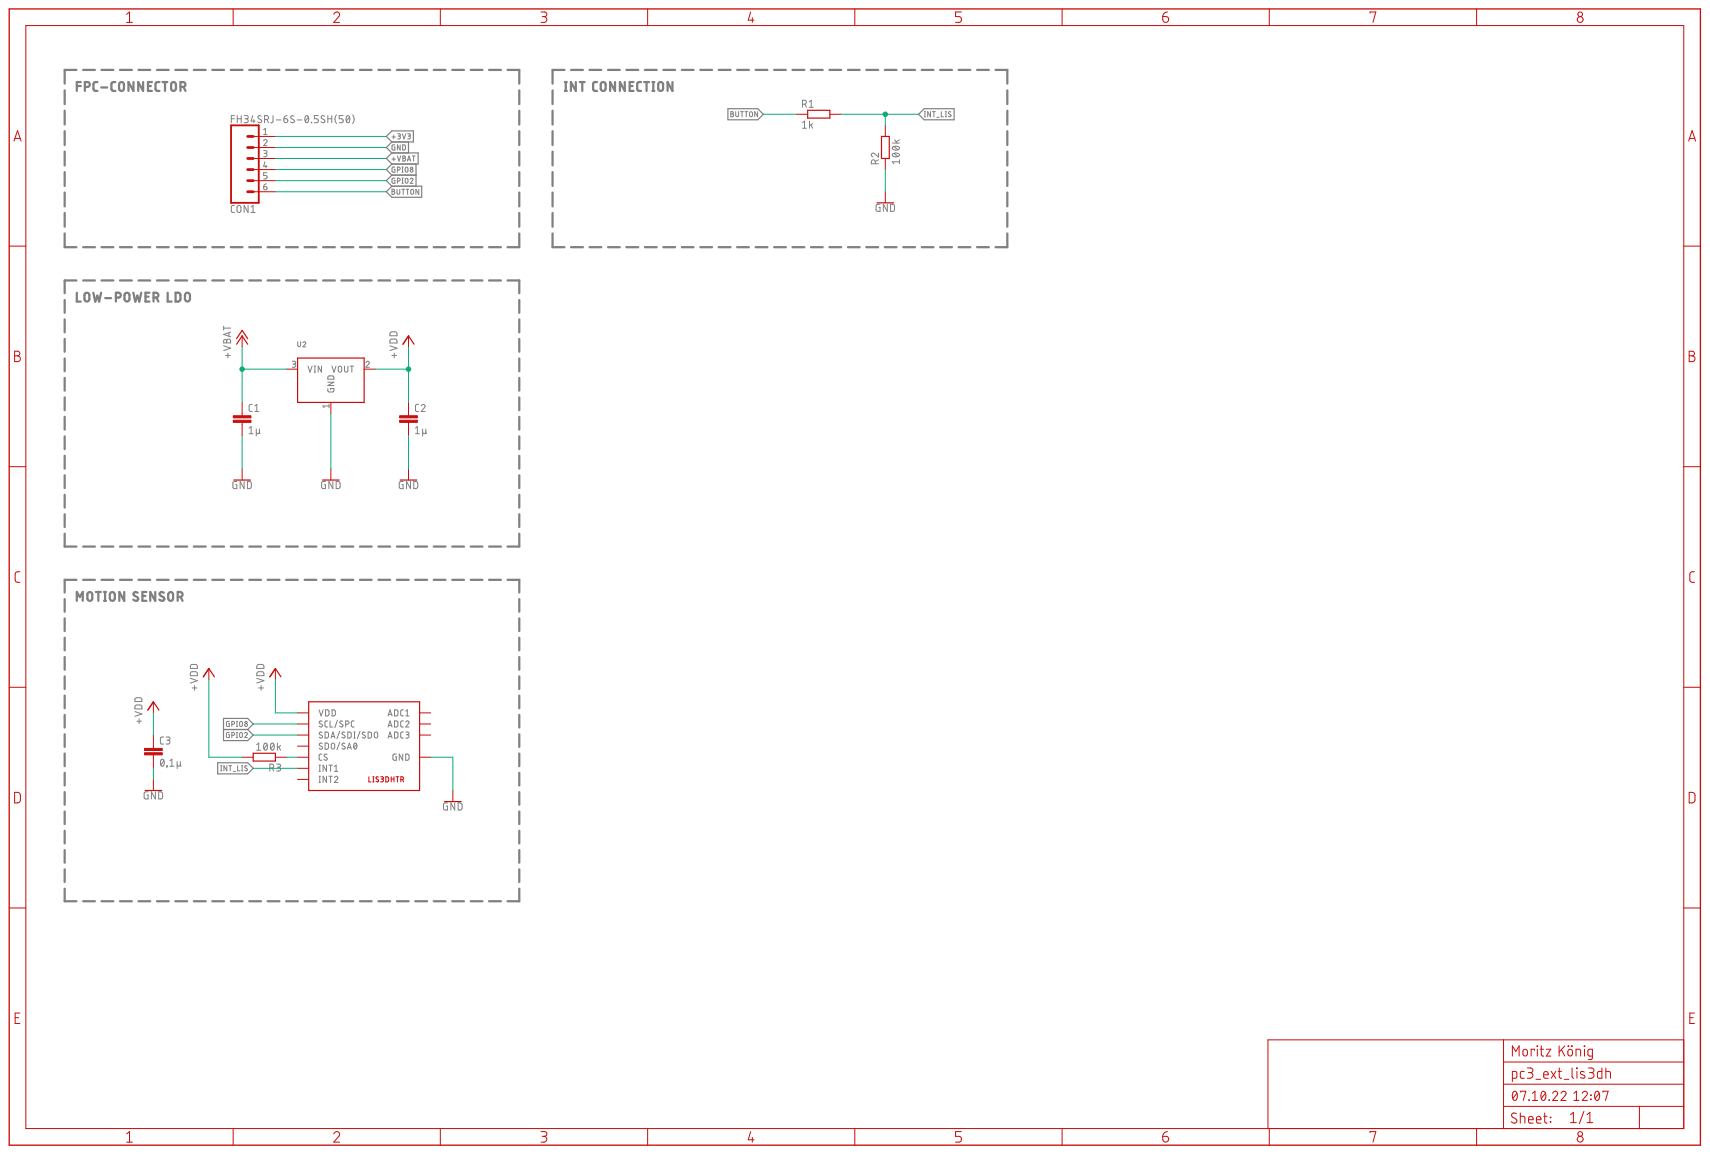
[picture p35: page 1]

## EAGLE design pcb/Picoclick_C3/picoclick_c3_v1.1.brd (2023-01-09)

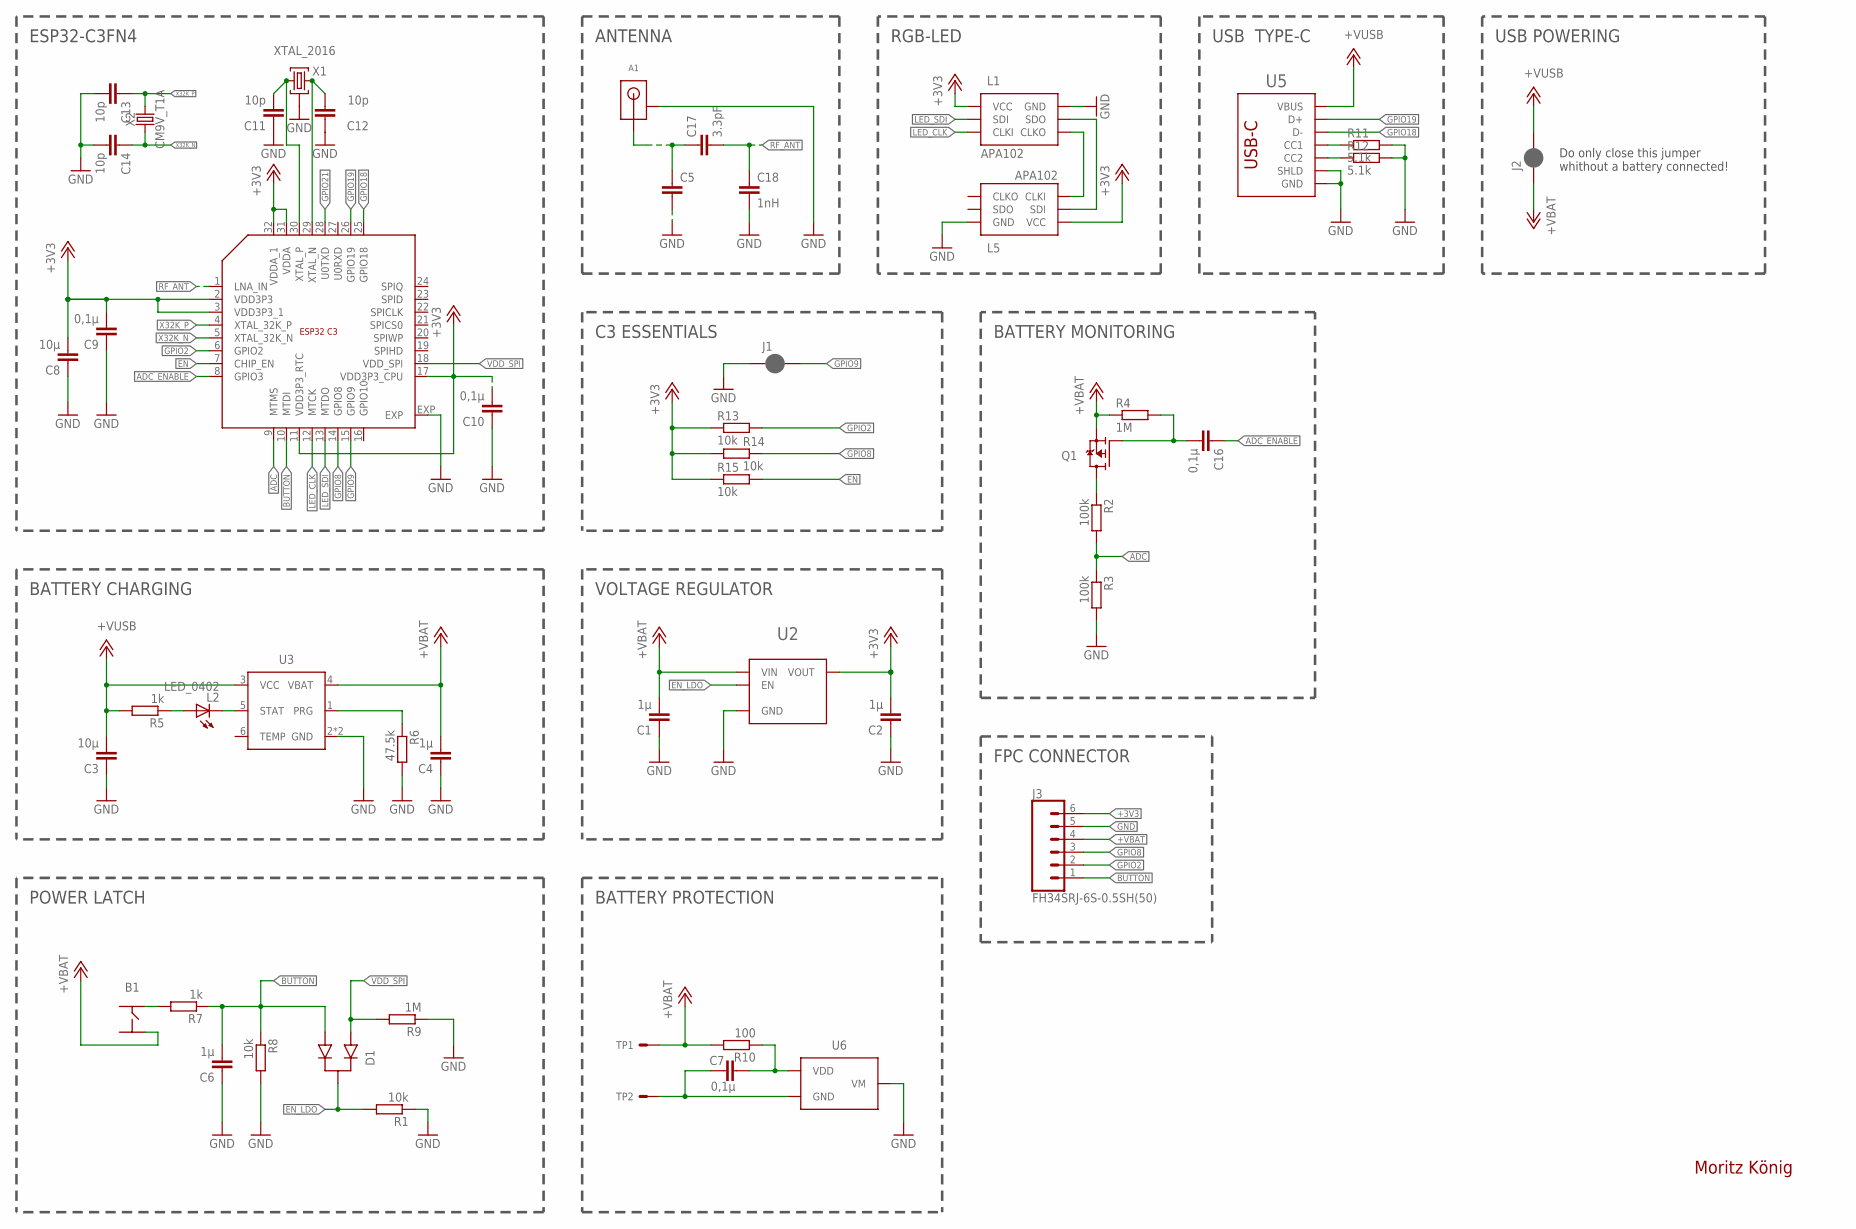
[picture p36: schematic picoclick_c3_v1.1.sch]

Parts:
A1: RFECA3216060A1T_NEW3_M
B1: BUTTON_4PIN; BUTTON_SMD_12MM
C1, C2, C4, C6: 1µ; C0402_S
C3, C8: 10µ; C0402_S
C5: C0402_S
C7, C9, C10, C16: 0,1µ; C0402_S
C11, C12, C13, C14: 10p; C0402_S
C17: 3.3pF; C0402_S
C18: 1nH; C0402_S
D1: DAN222; SOT523
J1: SMT_JUMPER_2_NC_PASTE; JUMPER_SMALL
J2: JUMPER_SMALL
J3: FH34SRJ-6S-0.5SH(50)
L1, L5: APA102_2020
L2: LED_0402; CHIPLED_0402
Q1: WPM2031+SOT1123; SOT723+1123
R1, R8, R13, R14, R15: 10k; R0402
R2, R3: 100k; R0402
R4, R9: 1M; R0402
R5, R7: 1k; R0402
R6: 47.5k; R0402
R10: 100; R0402
R11, R12: 5.1k; R0402
TP1, TP2: TP/SP-1.5X2.0; SOLDERPAD_1.5X2.0
U1: ESP32_C3_QFN32; QFN32
U2: MIC5504; TDFN4
U3: WS4518D; DFN-6
U5: USB_C_C393939; USBC_C393939
U6: XB6042I2SV; TDFN4
X1: XTAL_2016
X2: CM9V_T1A; XTAL_1016

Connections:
+3V3: C2.P$2 (2), C8.P$2 (2), C9.P$2 (2), C10.P$2 (2), J3.6, L1.P1 (VCC), L1.P1.1 (VCC), L5.P1 (VCC), L5.P1.1 (VCC), R13.1, R14.1, R15.1, U1.2 (VDD3P3), U1.3 (VDD3P3_1), U1.11 (VDD3P3_RTC), U1.17 (VDD3P3_CPU), U1.31 (VDDA), U1.32 (VDDA_1), U2.P1 (VOUT)
+VBAT: B1.P4 (4), C1.P$2 (2), C4.P$2 (2), J2.P$1 (1), J3.4, Q1.P$2 (S), R4.1, R10.2, TP1.1, U2.P4 (VIN), U3.4 (VBAT)
+VUSB: C3.P$2 (2), J2.P$2 (2), R5.2, U3.3 (VCC), U5.A4B9 (VBUS), U5.B4A9 (VBUS)
ADC: R2.2, R3.1, U1.9 (MTMS)
ADC_ENABLE: C16.P$1 (1), U1.8 (GPIO3)
BUTTON: C6.P$2 (2), D1.2, J3.1, R7.1, R8.1, U1.10 (MTDI)
EN: R15.2, U1.7 (CHIP_EN)
EN_LDO: D1.3, R1.2, U2.P3 (EN)
GND: A1.PGND1 (GND), A1.PGND2 (GND), C1.P$1 (1), C2.P$1 (1), C3.P$1 (1), C4.P$1 (1), C5.P$2 (2), C6.P$1 (1), C8.P$1 (1), C9.P$1 (1), C10.P$1 (1), C11.P$1 (1), C12.P$1 (1), C13.P$2 (2), C14.P$2 (2), C18.P$2 (2), J1.P$1 (1), J3.5, L1.P6 (GND), L1.P6.1 (GND), L5.P6 (GND), L5.P6.1 (GND), R1.1, R3.2, R6.2, R8.2, R9.1, R11.2, R12.2, U1.EXP, U2.EXP (GND), U2.P2 (GND), U3.2 (GND), U3.EXP (GND), U5.A1B12 (GND), U5.B1A12 (GND), U5.S1 (SHLD), U5.S2 (SHLD), U5.S3 (SHLD), U5.S4 (SHLD), U6.P4 (VM), X1.P2 (G), X1.P4 (G)
GPIO2: J3.2, R13.2, U1.6 (GPIO2)
GPIO8: J3.3, R14.2, U1.14 (GPIO8)
GPIO9: J1.P$2 (2), U1.15 (GPIO9)
GPIO18: U1.25 (GPIO18), U5.A7 (D-), U5.B7 (D-)
GPIO19: U1.26 (GPIO19), U5.A6 (D+), U5.B6 (D+)
GPIO21: U1.28 (U0TXD)
LED_CLK: L1.P5 (CLKI), U1.12 (MTCK)
LED_SDI: L1.P4 (SDI), U1.13 (MTDO)
unnamed: L1.P3 (SDO), L5.P4 (SDI)
unnamed: R6.1, U3.1 (PRG)
unnamed: R12.1, U5.B5 (CC2)
unnamed: L1.P2 (CLKO), L5.P5 (CLKI)
unnamed: R11.1, U5.A5 (CC1)
unnamed: A1.PFEED (ANT), C5.P$1 (1), C17.P$1 (1)
unnamed: C11.P$2 (2), U1.30 (XTAL_P), X1.P1 (1)
unnamed: C12.P$2 (2), U1.29 (XTAL_N), X1.P3 (2)
unnamed: B1.P2 (2), R7.2
unnamed: L2.P$2 (A), R5.1
unnamed: L2.P$1 (C), U3.5 (STAT)
unnamed: Q1.P$3 (D), R2.1
unnamed: C16.P$2 (2), Q1.P$1 (G), R4.2
unnamed: C7.P$2 (2), R10.1, U6.P1 (VDD)
unnamed: C7.P$1 (1), TP2.1, U6.EXP (GND), U6.P2 (GND), U6.P3 (GND)
RF_ANT: C17.P$2 (2), C18.P$1 (1), U1.1 (LNA_IN)
VDD_SPI: D1.1, R9.2, U1.18 (VDD_SPI)
X32K_N: C14.P$1 (1), U1.5 (XTAL_32K_N), X2.P$1 (1)
X32K_P: C13.P$1 (1), U1.4 (XTAL_32K_P), X2.P$2 (2)

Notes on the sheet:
Do only close this jumper whithout a battery connected!
Moritz König
BATTERY MONITORING
ANTENNA
USB TYPE-C
VOLTAGE REGULATOR
RGB-LED
POWER LATCH
C3 ESSENTIALS
BATTERY CHARGING
ESP32-C3FN4
BATTERY PROTECTION
USB POWERING
FPC CONNECTOR

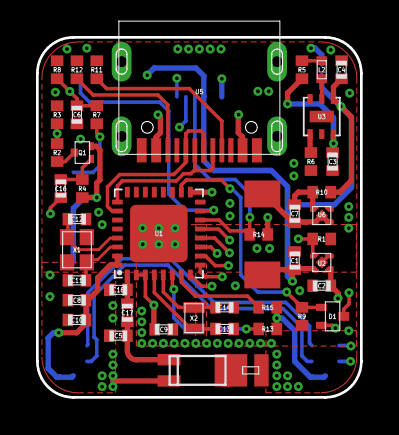
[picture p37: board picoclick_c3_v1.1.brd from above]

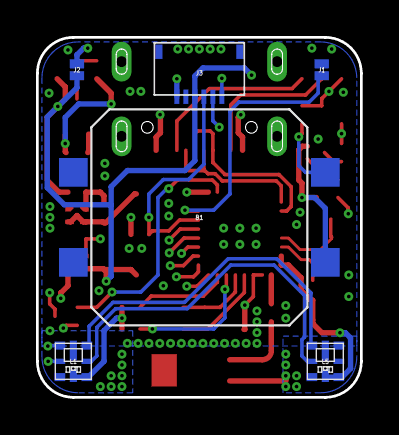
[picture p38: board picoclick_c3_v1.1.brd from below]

Board: 4 copper layers, 18.0 x 20.0 mm, 51 parts (6 on the bottom side), 35 nets.

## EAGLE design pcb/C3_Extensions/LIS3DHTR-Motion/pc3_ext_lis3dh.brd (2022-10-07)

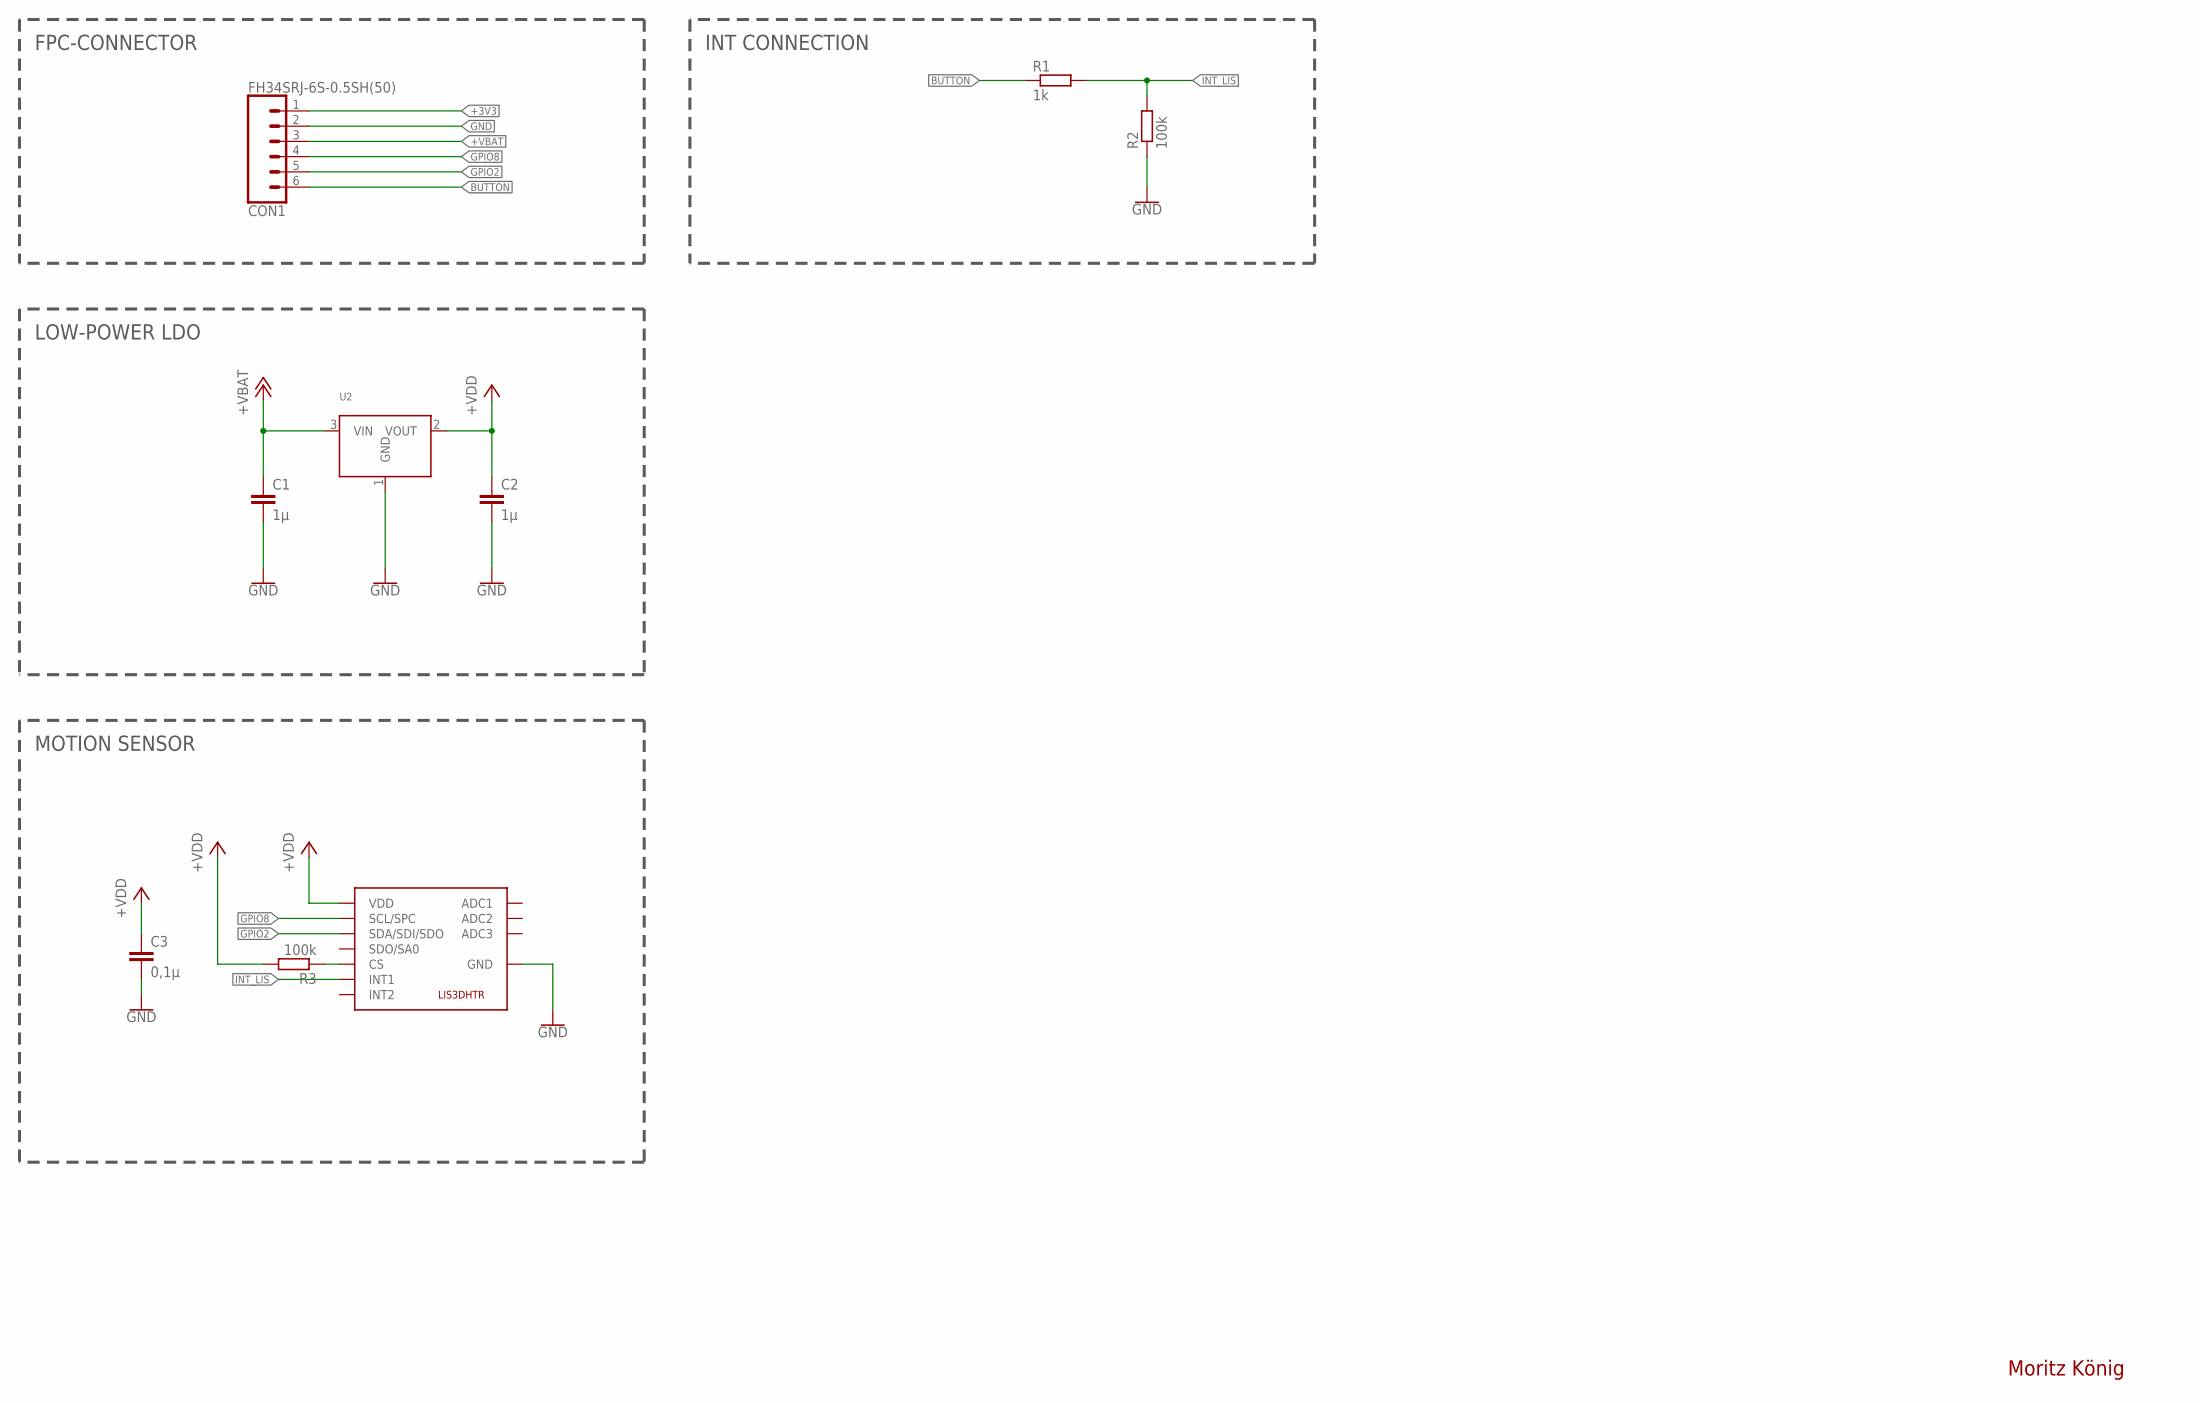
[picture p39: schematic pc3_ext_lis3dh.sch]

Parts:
C1, C2: 1µ; C0402_S
C3: 0,1µ; C0402_S
CON1: FH34SRJ-6S-0.5SH(50)
R1: 1k; R0402
R2, R3: 100k; R0402
U1: LIS3DHTR; LGA_16_LIS3DHTR
U2: SE82XX; SOT23-3

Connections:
+3V3: CON1.1
+VBAT: C1.P$1 (1), CON1.3, U2.3 (VIN)
+VDD: C2.P$1 (1), C3.P$1 (1), R3.2, U1.P$1 (VDD), U1.P$14 (VDD), U2.2 (VOUT)
BUTTON: CON1.6, R1.1
GND: C1.P$2 (2), C2.P$2 (2), C3.P$2 (2), CON1.2, R2.1, U1.P$5 (GND), U1.P$10 (GND), U1.P$12 (GND), U2.1 (GND)
GPIO2: CON1.5, U1.P$6 (SDA/SDI/SDO)
GPIO8: CON1.4, U1.P$4 (SCL/SPC)
INT_LIS: R1.2, R2.2, U1.P$11 (INT1)
unnamed: R3.1, U1.P$8 (CS)

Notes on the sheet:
Moritz König
FPC-CONNECTOR
LOW-POWER LDO
MOTION SENSOR
INT CONNECTION

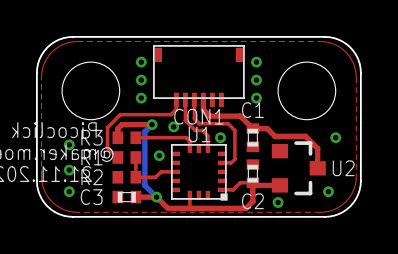
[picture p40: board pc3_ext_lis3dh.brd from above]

Board: 2 copper layers, 18.0 x 10.0 mm, 9 parts (0 on the bottom side), 8 nets.

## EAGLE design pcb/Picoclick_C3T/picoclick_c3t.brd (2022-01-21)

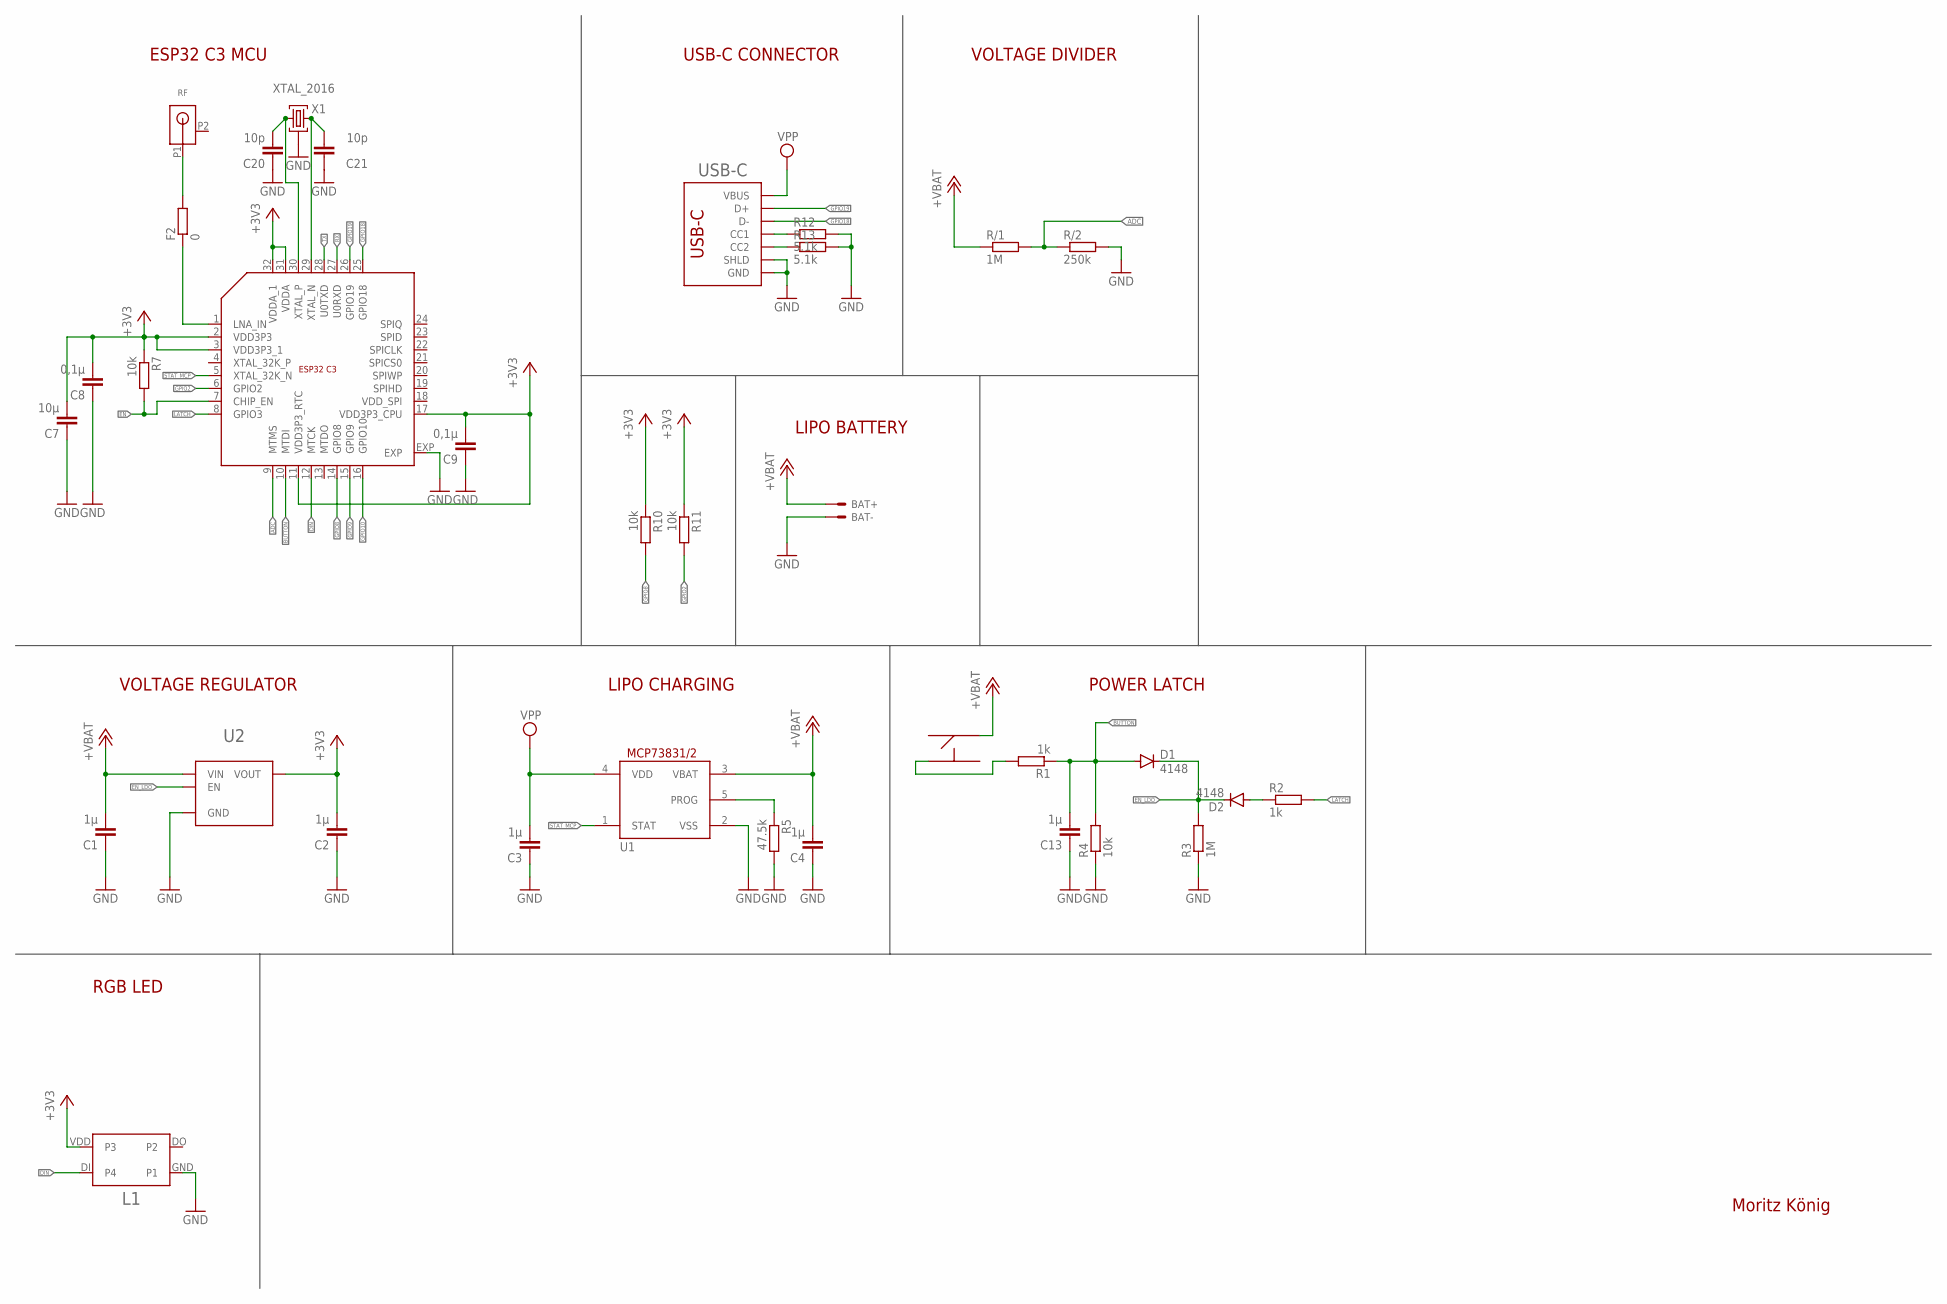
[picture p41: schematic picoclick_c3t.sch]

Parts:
BAT+: TP/SP-1.5X1.0; SOLDERPAD_1.5X1.0
BAT-: TP/SP-1.5X1.0; SOLDERPAD_1.5X1.0
C1, C2, C3, C4, C13: 1µ; C0402_S
C7: 10µ; C0402_S
C8, C9: 0,1µ; C0402_S
C20, C21: 10p; C0402_S
D1, D2: 4148; SOD523
ESP1: ESP32_C3_QFN32; QFN32
F2: 0; R0402
L1: WS2812_2020
R1, R2: 1k; R0402
R3: 1M; R0402
R4, R7, R10, R11: 10k; R0402
R5: 47.5k; R0402
R12, R13: 5.1k; R0402
R/1: 1M; R0402
R/2: 250k; R0402
RF: ANT3216LL00R2400A
U1: BRCL4054BME; SOT23-5
U2: MIC5504; TDFN4
U$1: BUTTON_ST-1187-3
USB-C: USB_C_C393939; USBC_C393939
X1: XTAL_2016; XTYL_2016

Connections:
+3V3: C2.P$2 (2), C7.P$2 (2), C8.P$2 (2), C9.P$2 (2), ESP1.2 (VDD3P3), ESP1.3 (VDD3P3_1), ESP1.11 (VDD3P3_RTC), ESP1.17 (VDD3P3_CPU), ESP1.31 (VDDA), ESP1.32 (VDDA_1), L1.VDD (P3), R7.1, R10.1, R11.1, U2.P1 (VOUT)
+VBAT: BAT+.1, C1.P$2 (2), C4.P$2 (2), R/1.1, U1.3 (VBAT), U2.P4 (VIN), U$1.P2
ADC: ESP1.9 (MTMS), R/1.2, R/2.1
BUTTON: C13.P$2 (2), D1.A, ESP1.10 (MTDI), R1.1, R4.2
DIN: ESP1.12 (MTCK), L1.DI (P4)
EN: ESP1.7 (CHIP_EN), R7.2
EN_LDO: D1.C, D2.C, R3.2, U2.P3 (EN)
GND: BAT-.1, C1.P$1 (1), C2.P$1 (1), C3.P$1 (1), C4.P$1 (1), C7.P$1 (1), C8.P$1 (1), C9.P$1 (1), C13.P$1 (1), C20.P$1 (1), C21.P$1 (1), ESP1.EXP, L1.GND (P1), R3.1, R4.1, R5.2, R12.2, R13.2, R/2.2, U1.2 (VSS), U2.EXP (GND), U2.P2 (GND), USB-C.A1B12 (GND), USB-C.B1A12 (GND), USB-C.S1 (SHLD), USB-C.S2 (SHLD), USB-C.S3 (SHLD), USB-C.S4 (SHLD), X1.P2 (G), X1.P4 (G)
GPIO2: ESP1.6 (GPIO2), R11.2
GPIO8: ESP1.14 (GPIO8), R10.2
GPIO9: ESP1.15 (GPIO9)
GPIO10: ESP1.16 (GPIO10)
GPIO18: ESP1.25 (GPIO18), USB-C.A7 (D-), USB-C.B7 (D-)
GPIO19: ESP1.26 (GPIO19), USB-C.A6 (D+), USB-C.B6 (D+)
LATCH: ESP1.8 (GPIO3), R2.2
unnamed: R1.2, U$1.P3
unnamed: ESP1.1 (LNA_IN), F2.1
unnamed: F2.2, RF.P1 (ANT)
unnamed: D2.A, R2.1
unnamed: R13.1, USB-C.B5 (CC2)
unnamed: R5.1, U1.5 (PROG)
unnamed: R12.1, USB-C.A5 (CC1)
unnamed: C20.P$2 (2), ESP1.30 (XTAL_P), X1.P1 (1)
unnamed: C21.P$2 (2), ESP1.29 (XTAL_N), X1.P3 (2)
RX: ESP1.27 (U0RXD)
STAT_MCP: ESP1.5 (XTAL_32K_N), U1.1 (STAT)
TX: ESP1.28 (U0TXD)
VPP: C3.P$2 (2), U1.4 (VDD), USB-C.A4B9 (VBUS), USB-C.B4A9 (VBUS)

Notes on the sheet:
Moritz König
VOLTAGE DIVIDER
LIPO CHARGING
VOLTAGE REGULATOR
POWER LATCH
RGB LED
USB-C CONNECTOR
ESP32 C3 MCU
LIPO BATTERY

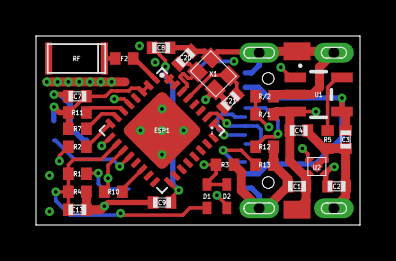
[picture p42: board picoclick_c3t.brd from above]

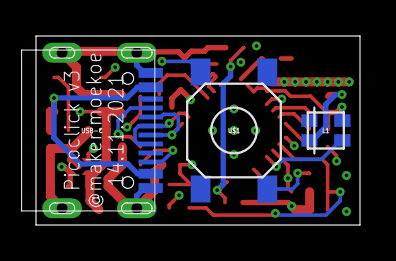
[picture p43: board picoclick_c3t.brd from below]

Board: 4 copper layers, 18.0 x 10.5 mm, 35 parts (3 on the bottom side), 24 nets.

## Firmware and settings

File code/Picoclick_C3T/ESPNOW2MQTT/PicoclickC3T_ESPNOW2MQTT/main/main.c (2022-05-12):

#include <stdio.h>
#include <stdlib.h>
#include <string.h>
#include <freertos/FreeRTOS.h>
#include <freertos/task.h>
#include "freertos/event_groups.h"
#include <driver/gpio.h>
#include <driver/adc.h>

#include "led_strip.h"
#include "nvs_flash.h"
#include "esp_event.h"
#include "esp_netif.h"
#include "esp_wifi.h"
#include "esp_log.h"
#include "esp_system.h"
#include "esp_now.h"
#include "esp_sleep.h"

#include "sdkconfig.h"

#include "espnow_basic_config.h"

static const char *TAG = "Basic_Slave";

void my_data_populate(my_data_t *data);

static EventGroupHandle_t s_evt_group;

#define MY_ESPNOW_WIFI_MODE WIFI_MODE_STA
#define MY_ESPNOW_WIFI_IF   ESP_IF_WIFI_STA

#define ESPNOW_ID 4567
#define SINGLE_TAP_DURATION    1000 // 0 to disable, else delay in ms
int bat_level = 0;

void my_data_populate(my_data_t *data){
    ESP_LOGI(TAG, "Populating my_data_t");
    data->id = ESPNOW_ID;
    data->value = 1;
    data->battery_level = bat_level;
    data->single_tap_duration = SINGLE_TAP_DURATION;
}

static void packet_sent_cb(const uint8_t *mac_addr, esp_now_send_status_t status){
    if (mac_addr == NULL) {
        ESP_LOGE(TAG, "Send cb arg error");
        return;
    }

    assert(status == ESP_NOW_SEND_SUCCESS || status == ESP_NOW_SEND_FAIL);
    xEventGroupSetBits(s_evt_group, BIT(status));
}

static void init_espnow_slave(void){
    const wifi_init_config_t cfg = WIFI_INIT_CONFIG_DEFAULT();
    esp_err_t ret = nvs_flash_init();
    if (ret == ESP_ERR_NVS_NO_FREE_PAGES || ret == ESP_ERR_NVS_NEW_VERSION_FOUND) {
        ESP_ERROR_CHECK( nvs_flash_erase() );
        ret = nvs_flash_init();
    }
    ESP_ERROR_CHECK( ret );
    ESP_ERROR_CHECK( esp_netif_init() );
    ESP_ERROR_CHECK( esp_event_loop_create_default() );
    ESP_ERROR_CHECK( esp_wifi_init(&cfg) );
    ESP_ERROR_CHECK( esp_wifi_set_storage(WIFI_STORAGE_RAM) );
    ESP_ERROR_CHECK( esp_wifi_set_mode(MY_ESPNOW_WIFI_MODE) );
    ESP_ERROR_CHECK( esp_wifi_start() );
#if MY_ESPNOW_ENABLE_LONG_RANGE
    ESP_ERROR_CHECK( esp_wifi_set_protocol(MY_ESPNOW_WIFI_IF, WIFI_PROTOCOL_11B|WIFI_PROTOCOL_11G|WIFI_PROTOCOL_11N|WIFI_PROTOCOL_LR) );
#endif
    ESP_ERROR_CHECK( esp_now_init() );
    ESP_ERROR_CHECK( esp_now_register_send_cb(packet_sent_cb) );
    ESP_ERROR_CHECK( esp_now_set_pmk((const uint8_t *)MY_ESPNOW_PMK) );

    // Alter this if you want to specify the gateway mac, enable encyption, etc
    const esp_now_peer_info_t broadcast_destination = {
        .peer_addr = MY_RECEIVER_MAC,
        .channel = MY_ESPNOW_CHANNEL,
        .ifidx = MY_ESPNOW_WIFI_IF
    };
    ESP_ERROR_CHECK( esp_now_add_peer(&broadcast_destination) );
}

static esp_err_t send_espnow_data(void){
    const uint8_t destination_mac[] = MY_RECEIVER_MAC;
    static my_data_t data;

    // Go to the user function to populate the data to send
    my_data_populate(&data);

    // Send it
    ESP_LOGI(TAG, "Sending %u bytes to " MACSTR, sizeof(data), MAC2STR(destination_mac));
    esp_err_t err = esp_now_send(destination_mac, (uint8_t*)&data, sizeof(data));
    if(err != ESP_OK){
        ESP_LOGE(TAG, "Send error (%d)", err);
        return ESP_FAIL;
    }

    // Wait for callback function to set status bit
    EventBits_t bits = xEventGroupWaitBits(s_evt_group, BIT(ESP_NOW_SEND_SUCCESS) | BIT(ESP_NOW_SEND_FAIL), pdTRUE, pdFALSE, 2000 / portTICK_PERIOD_MS);
    if(!(bits & BIT(ESP_NOW_SEND_SUCCESS))){
        if (bits & BIT(ESP_NOW_SEND_FAIL)){
            ESP_LOGE(TAG, "Send error");
            return ESP_FAIL;
        }
        ESP_LOGE(TAG, "Send timed out");
        return ESP_ERR_TIMEOUT;
    }

    ESP_LOGI(TAG, "Sent!");
    return ESP_OK;
}


static led_strip_t *pStrip_a;
static uint8_t s_led_state = 0;

#define STAT_MCP_PIN    1
#define LATCH_PIN       3
#define ADC_PIN         ADC1_CHANNEL_4
#define BTN_PIN         5
#define LED_PIN         6

#define NUM_LEDS        1
#define LED_RMT_CHANNEL 0


static void configure_led(void){
    pStrip_a = led_strip_init(LED_RMT_CHANNEL, LED_PIN, NUM_LEDS);
    // pStrip_a->clear(pStrip_a, 100);
}

int app_main(){
    gpio_reset_pin(LATCH_PIN);
    gpio_set_direction(LATCH_PIN, GPIO_MODE_OUTPUT);
    gpio_set_level(LATCH_PIN, true);

    configure_led();

    vTaskDelay(20 / portTICK_PERIOD_MS);

    printf("Hello world!\n");

    init_espnow_slave();

    pStrip_a->set_pixel(pStrip_a, 0, 0, 50, 0);
    pStrip_a->refresh(pStrip_a, 100);

    s_evt_group = xEventGroupCreate();
    assert(s_evt_group);

    int raw = 0;
    int sum = 0;
    for(int i=0; i<100; i++){
        raw = adc1_get_raw(ADC_PIN);
        sum += raw;
    }
    bat_level = sum/100;

    send_espnow_data();

    esp_wifi_deinit();
    esp_wifi_stop();
    
    vTaskDelay(300 / portTICK_PERIOD_MS);

    // pStrip_a->set_pixel(pStrip_a, 0, 0, 50, 0);
    // pStrip_a->refresh(pStrip_a, 100);
    // vTaskDelay(500 / portTICK_PERIOD_MS);

    // pStrip_a->set_pixel(pStrip_a, 0, 0, 0, 50);
    // pStrip_a->refresh(pStrip_a, 100);
    // vTaskDelay(500 / portTICK_PERIOD_MS);
    // adc1_config_width(ADC_WIDTH_12Bit);
    // adc1_config_channel_atten(ADC_PIN, ADC_ATTEN_0db);


    gpio_set_level(LATCH_PIN, false);
    // esp_deep_sleep_enable_timer_wakeup(10000);
    // esp_deep_sleep_start();

    while(true){
        int val = adc1_get_raw(ADC_PIN);                                                                                                                                                                                                                                                                                                                                                                                                                                                                                                                                                                                                                                                                                                                                                                                                                                                                                                                                                                                                                                                                                                                                                                                                                                                                                                                                                                                                                                                                                                                                                                                                                                                                                                                                                                                                                                                                                                                                                                                                                                                                                                                                                                                                                                                                                                                                                                                                                                                                                                                                                                                                                                                                                                                                                                                                                                                                                                                                                                                                                                                                                                                                                                                                                                                                                                                                                                                                                                                                                                                                                                                                                                                                                                                                                                                                                                                                                                                                                                                                                                                                                                                                                                                                                                                                                                                                                                                                                                                                                                                                                                                                                                                                                                                                                                                                                                                                                                                                                                                                                                                                                                                                                                                                                                                                                                                                                                                                                                                                                                                                                                                                                                                                                                                                                                                                                                                                                                                                                                                                                                                                                                                                                                                                                                                                                                                                                                                                                                                                                                                                                                                                                                                                                                                                                                                                                                                                                                                                                                                                                                                                                                                                                                                                                                                                                                                                                                                                                                                                                                                                                                                                                                                                                                                                                                                                                                                                                                                                                                                                                                                                                                                                                                                                                                                                                                                                                                                                                                                                                                                                                                                                                                                                                                                                                                                                                                                                                                                                                                                                                                                                                                                                                                                                                                     
        printf("Voltage: %i\n", val);

        if(s_led_state){
            pStrip_a->set_pixel(pStrip_a, 0, 50, 0, 0);
        }
        else{
            pStrip_a->set_pixel(pStrip_a, 0, 0, 0, 0);
        }
        pStrip_a->refresh(pStrip_a, 100);
        s_led_state = !s_led_state;
        vTaskDelay(300 / portTICK_PERIOD_MS);
    }
}

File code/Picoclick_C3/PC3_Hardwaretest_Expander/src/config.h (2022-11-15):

// Picoclick C3 hardware definitions
#define ADC_ENABLE_PIN  3
#define APA102_SDI_PIN  7
#define APA102_CLK_PIN  6
#define ADC_PIN         4
#define BUTTON_PIN      5

#define FPC_IO_1        2
#define FPC_IO_2        8
#define FPC_IO_BTN      BUTTON_PIN

#define SDA_PIN         FPC_IO_1
#define SCL_PIN         FPC_IO_2

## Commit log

2022-01-09 added power measurements
2022-01-11 added gerbers, bom, battery info
    [picoclick_c3t_v1_bom.csv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]
2022-01-14 added PC3T 3D files
    [Picoclick_C3T_PCB.3mf, Picoclick_C3T_PCB.f3z, Picoclick_C3T_PCB.stl]
2022-01-14 uploaded case design 1
    [pc3t_case1_bot.stl, pc3t_case1_top.stl]
2022-01-17 added boards description
2022-01-21 added eagle board files
    [picoclick_c3t.brd, picoclick_c3t.sch]
2022-01-24 added optimized hardware test code
    with battery reading
2022-01-25 added pogo flasher
    [Picoclick_C3T_Flash_Pogo_Adapter.stl]
2022-04-25 added pin1 markings of ldo, mcu and antenna
2022-05-22 added round case files
    [pc3t_case2_round_bot.stl, pc3t_case2_round_top.stl]
2022-05-22 added two versions of a keyring case
    [pc3t_case2_round_bot_keyring1.stl, pc3t_case2_round_bot_keyring2.stl, pc3t_case2_round_top_keyring.stl]
2022-05-22 removed old case top part
    [pc3t_case2_round_top.stl, pc3t_case2_round_top_keyring.stl]
2022-07-08 preparation for the Picoclick-C3 release
    [Picoclick_C3T_Flash_Pogo_Adapter.stl, Picoclick_C3T_PCB.3mf, Picoclick_C3T_PCB.f3z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]
2022-07-14 added first c3 case
    [picoclick_c3_clear_bot.stl, picoclick_c3_clear_top.stl]
2022-07-14 added board overview for the C3
2022-08-05 list all extension boards
2022-08-05 added pictures of extension boards
2022-08-10 added vcnl4040 extension board
2022-09-21 added battery monitoring description
2022-09-22 added power reducing chapter to docs
2022-10-07 added new clear case
    - more space for the battery
    - lock mechanism for bot and top
    [picoclick_c3_clear_bot_batspace_lock.stl, picoclick_c3_clear_top_batspace_lock.stl]
2022-10-07 added motion extension board pcb files
    [pc3_ext_lis3dh.brd, pc3_ext_lis3dh.sch]
2022-12-02 added cases for ext motion, oled049 and pir; add gif for expander extention
    [pc3_ext_motion_v2.stl, pc3_ext_oled049_v1.stl, pc3_ext_pir_v1.stl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]
2023-01-09 added board files for the C3
    [picoclick_c3_v1.1.brd, picoclick_c3_v1.1.sch]
2023-02-19 added 3D model PC3 PCB as step file
    [PC3_3Dmodel.step]
